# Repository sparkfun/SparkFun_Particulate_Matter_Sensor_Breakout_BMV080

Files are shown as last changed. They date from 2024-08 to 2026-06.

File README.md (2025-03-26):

SparkFun Air Quality PM1/PM2.5/PM10 Sensor - BMV080 (Qwiic)
========================================

SparkFun Air Quality PM1/PM2.5/PM10 Sensor - BMV080 (Qwiic) (https://www.sparkfun.com/sparkfun-air-quality-pm1-pm2-5-pm10-sensor-bmv080-qwiic.html)

[*SparkFun Air Quality PM1/PM2.5/PM10 Sensor - BMV080 (Qwiic) (SEN-26554)*](https://www.sparkfun.com/sparkfun-air-quality-pm1-pm2-5-pm10-sensor-bmv080-qwiic.html)

The SparkFun Qwiic Particulate Matter Sensor - BMV080 is an ultra-small, fan-less air quality sensor for sensing PM2.5 particulate matter! Within the enclosure is a breakout board that breaks out Bosch's BMV080, the world's smallest PM1 and PM2.5 air quality sensor. The sensing element measures merely 4.2mm x 3.5mm x 3.1mm (W x L x H), which is more than 450 times smaller than any comparable device on the market. The innovative design is based on ultra-compact lasers with integrated photodiodes. The sensor applies sophisticated algorithms to measure PM1 and PM2.5 concentrations directly in free space, without requiring an intrusive fan.

Repository Contents
-------------------

* **.github/workflows** - YAML files used for GitHub Actions and GitHub Pages/mkdocs
* **/Enclosure** - Enclosure files
* **/Hardware** - KiCad design files (.kicad_pcb, .kicad_sch, .kicad_pro)
  * **/Production** - Production panel files (.kicad_pcb)
* **/docs** - Online documentation files
  * **/assets** - Folder containing all the file assets used for product documentation
    * **/board_files** - Copy of design files used for product documentation
    * **/component_documentation** - Datasheets and manuals for hardware components
    * **/img** - Images for product documentation
  * **/github** - Files stating how to contribute and filing issues used for product documentation
  * **/javascript** - Folder containing custom javascript used for product documentation
  * **/stylesheet** - Folder containing CSS files used for product documentation
* **/overrides** - Customization files used for product documentation
  * **/.icons** - Icons used for GitHub used for product documentation
  * **./partials** - Used for product documentation

Documentation
--------------
* **[Library](https://github.com/sparkfun/SparkFun_BMV080_Arduino_Library/)** - Arduino library for the SparkFun Air Quality PM1/PM2.5/PM10 Sensor - BMV080 (Qwiic).
* **[Hookup Guide](https://docs.sparkfun.com/SparkFun_Particulate_Matter_Sensor_Breakout_BMV080)** - Basic hookup guide for the SparkFun Air Quality PM1/PM2.5/PM10 Sensor - BMV080 (Qwiic).

Product Versions
----------------
* [SEN-26554](https://www.sparkfun.com/products/ - SparkFun Air Quality PM1/PM2.5/PM10 Sensor - BMV080 (Qwiic) 

License Information
-------------------

This product is _**open source**_!

Please review the LICENSE.md file for license information.

If you have any questions or concerns on licensing, please contact technical support on our [SparkFun forums](https://community.sparkfun.com/c/community/general-chit-chat/37).

Distributed as-is; no warranty is given.

- Your friends at SparkFun.

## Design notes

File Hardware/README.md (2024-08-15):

SparkFun <PRODUCT NAME> Design Files
=====================================

The .sch and .brd files hare are Eagle CAD schematic and PCB design files from SparkFun Electronics.
A freeware version of Autodesk Eagle can be found [here](https://www.autodesk.com/products/eagle/free-download).

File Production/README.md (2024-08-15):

SparkFun <PRODUCT NAME> Production Files
=========================================

These are the production files SparkFun uses for printing PCBs.

License Information
-------------------
This product is open source! 

The hardware is released under [Creative Commons ShareAlike 4.0 International](https://creativecommons.org/licenses/by-sa/4.0/).

Please use, reuse, and modify these files as you see fit. Please maintain attribution to SparkFun Electronics and release anything derivative under the same license.

Distributed as-is; no warranty is given.

- Your friends at SparkFun.

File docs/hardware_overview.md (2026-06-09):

In this section, we will highlight the hardware and pins that are broken out on the SparkFun Qwiic Air Quality PM1/PM2.5/PM10 Sensor - BMV080. For more information, check out our [Resources and Going Further](../resources/) on the components used for the sensor.

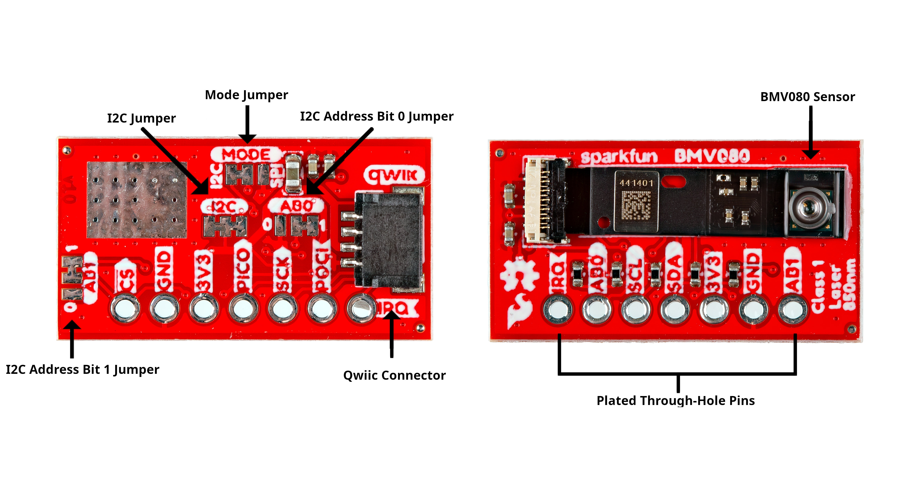
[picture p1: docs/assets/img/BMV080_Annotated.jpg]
Annotated photo of BMV080 Breakout


### BMV080

The breakout board comes with Bosch's BMV080 populated and takes advantage of its flexible cable with the FPC 13-pin 0.33mm connector. The sensor is an ultra-small, fan-less air quality sensor for sensing PM1, PM2.5 and PM10 concentrations. A special lens allows the laser to pass through the enclosure to take measurements.

!!! Note
    This is a [CLASS 1](https://en.wikipedia.org/wiki/Laser_safety#Class_1) LASER PRODUCT CLASSIFIED IEC 60825-1 2014.

### Power

To power the board, you will need **3.3V**. You can connect a Qwiic cable to the Qwiic connector. Or you could solder directly to the PTHs. Below are the power pins that are broken out on the edge of the board.

* **3V3** - This pin is the voltage input for the board. The recommended input voltage for this pin is 3.3V.
* **GND** - Of course, is the common, ground voltage (0V reference) for the system.

### Qwiic and I<sup>2</sup>C

By default, the communication interface is set to I<sup>2</sup>C with the MODE jumper. The board includes one horizontal Qwiic connector to connect to other Qwiic-enabled I<sup>2</sup>C devices. However, the board still breaks out 0.1"-spaced pins for users who prefer a soldered connection.

* **SCL/SCK** - On the top side, the pin is labeled as SCL. On the bottom side, the pin is labeled as SCK. Thus the pin is used for the I<sup>2</sup>C clock.
* **SDA/PICO** - On the top side, the pin is labeled as SDA. On the bottom side, the pin is labeled as PICO. Thus the pin is used for the I<sup>2</sup>C data.

The default address of the BMV080 is set to **0x57** by default. By configuring AB1 and AB0 jumpers, you can adjust the I<sup>2</sup>C address to an alternative address. For more information, check below under the jumpers.

### Interrupt Pin

The board includes an interrupt pin when the board is set to I<sup>2</sup>C mode.

* **IRQ** &mdash; Short for interrupt. This pin sends an interrupt signal to a microcontroller.

!!! note
    The hardware interrupt of the BMV080 sensor unit cannot be used as trigger
    in duty cycling mode.

### SPI

The BMV080 can also be set to SPI as the communication interface by adjusting the MODE jumper on the back.

* **PICO/SDA** - On the bottom side, the pin is labeled as PICO (i.e. Peripheral In, Controller Out). On the top side, the pin is labeled as SDA.
* **POCI/AB0** - On the bottom side, the pin is labeled as POCI (i.e. Peripheral Out, Controller In). On the top side, the pin is labeled as AB0. When set to SPI mode, make sure to leave AB0 (POCI) open!
* **SCK/SCL** - On the bottom side, the pin is labeled as SCK for the clock. On the tip side, the pin is labeled as SCL.
* <b><span style="text-decoration: overline">CS</span></b> - On the bottom side, the pin is labeled as <span style="text-decoration: overline">CS</span> (i.e. chip select). On the top side, the pin is labeled as AB1. This pin is active low. When set to SPI mode, make sure to leave AB1 (<span style="text-decoration: overline">CS</span>) open!

### Jumpers

!!!note
    If this is your first time working with jumpers, check out the [How to Work with Jumper Pads and PCB Traces](https://learn.sparkfun.com/tutorials/how-to-work-with-jumper-pads-and-pcb-traces/all) tutorial for more information.

The back of the board has four jumpers to configure the board labeled **I<sup>2</sup>C**, **AB0**, **AB1** and **MODE**.

* **I<sup>2</sup>C** - By default, this three-pad jumper is closed. The three way jumper labeled I<sup>2</sup>C connects 3.3V to two 2.2k&ohm; pull-up resistors and to the I<sup>2</sup>C data and clock lines. If multiple devices are connected to the bus with the pull-up resistors enabled, the parallel equivalent resistance will create too strong of a pull-up for the bus to operate correctly. As a general rule of thumb, [disable all but one pair of pull-up resistors](https://learn.sparkfun.com/tutorials/i2c/all#i2c-at-the-hardware-level) if multiple devices are connected to the bus.
* **AB0** - Address jumper 0 when the BMV080 is set to I<sup>2</sup>C mode. This is a multifunctional pin. This is also connected to POCI. By default, the three-pad jumper's center pad is connected to the `1` side
* **AB1** - Address jumper 1 when the BMV080 is set to I<sup>2</sup>C mode. This is a multifunctional pin. This is also connected to <span style="text-decoration: overline">CS</span>. By default, the three-pad jumper's center pad is connected to the `1` side
* **MODE** - By default, this three-pad jumper is closed between the center pad and the pad labeled as I2C. Thus, the communication interface is set to I<sup>2</sup>C. Cutting this trace and adding solder between the center pad and the pad labeled as SPI will configure the communication interface as SPI.

When the SparkFun Qwiic Air Quality Sensor is configured in I2C mode, users have the ability to configure the default address using AB0 and AB1 jumpers. The following table shows the possible I<sup>2</sup>C address based on the jumper configuration.

<div style="text-align: center;">
    <table>
        <tr>
            <th style="text-align: center; border: solid 1px #cccccc;">AB1
            </th>
            <th style="text-align: center; border: solid 1px #cccccc;">AB0
            </th>
            <th style="text-align: center; border: solid 1px #cccccc;">I<sup>2</sup>C Address
            </th>
        </tr>
        <tr>
            <td style="text-align: center; border: solid 1px #cccccc;">0
            </td>
            <td style="text-align: center; border: solid 1px #cccccc;">0
            </td>
            <td style="text-align: center; border: solid 1px #cccccc;">0x54
            </td>
        </tr>
        <tr>
            <td style="text-align: center; border: solid 1px #cccccc;">0
            </td>
            <td style="text-align: center; border: solid 1px #cccccc;">1
            </td>
            <td style="text-align: center; border: solid 1px #cccccc;">0x55
            </td>
        </tr>
        <tr>
            <td style="text-align: center; border: solid 1px #cccccc;">1
            </td>
            <td style="text-align: center; border: solid 1px #cccccc;">0
            </td>
            <td style="text-align: center; border: solid 1px #cccccc;">0x56
            </td>
        </tr>
        <tr>
            <td style="text-align: center; border: solid 1px #cccccc;">1
            </td>
            <td style="text-align: center; border: solid 1px #cccccc;">1
            </td>
            <td style="text-align: center; border: solid 1px #cccccc;"><b>0x57 (default)</b>
            </td>
        </tr>
    </table>
</div>

!!! note
    AB0 is a multifunctional pin! When the SparkFun Qwiic Air Quality Sensor is configured for SPI, make sure to leave AB0 (POCI) open!

### 3D Model

A 3D model of the board and components was exported to a STEP file using KiCad.

<!-- Import the component -->
<script type="module" src="https://ajax.googleapis.com/ajax/libs/model-viewer/3.5.0/model-viewer.min.js"></script>

    <model-viewer src="../assets/3d_model/SparkFun_BMV080_v10_3D_model.glb" camera-controls poster="../assets/3d_model/SparkFun_BMV080_v10_3D_image.jpg" environment-image="legacy" shadow-intensity="1.58" exposure="0.64" shadow-softness="0.24" tone-mapping="neutral" camera-orbit="-46.67deg 57.14deg 153.3m" field-of-view="30deg" style="width: 750px; height: 500px;">
    </model-viewer>

<br />
<div style="text-align: center">
    <a href="../assets/3d_model/SparkFun_BMV080_v10_3D_model.step" target="stp_file" class="md-button">Click Here for the STEP File</a>
</div>

### Board Dimensions

The board measures 0.5" x 0.95" (12.70mm x 24.13mm). The breakout board itself does not have mounting holes though the enclosure has two mounting slots to attach the sensor to your project.

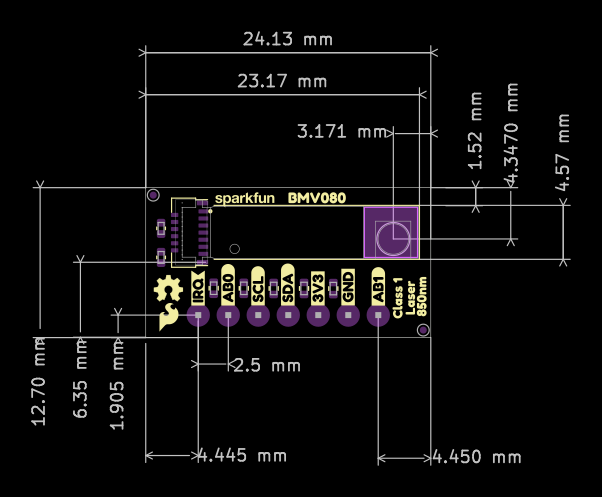
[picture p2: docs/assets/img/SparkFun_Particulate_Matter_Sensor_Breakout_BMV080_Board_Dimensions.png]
Board Dimensions


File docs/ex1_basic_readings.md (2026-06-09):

This example shows how to read the BMV080 via Qwiic when the sensor is configured in continuous mode. The output will show the amount of particulate matter that is detected.

Head to the example 1 from the Arduino IDE's menu (located in **File** **Examples** > **SparkFun BMV080 Arduino Library** > **Example_01_BasicReadings**).

If you have not already, select your Board (if you're following along with the suggested dev board for this tutorial, select **SparkFun ESP32 IoT RedBoard**), and associated COM port. Upload the code to the board and set the [Arduino Serial Monitor](https://learn.sparkfun.com/tutorials/terminal-basics/all#arduino-serial-monitor-windows-mac-linux) to **115200** baud. The Arduino should begin outputting the sensor readings. If the air in front of the sensor is void of particulate matter, you should see `0.00` for each size.

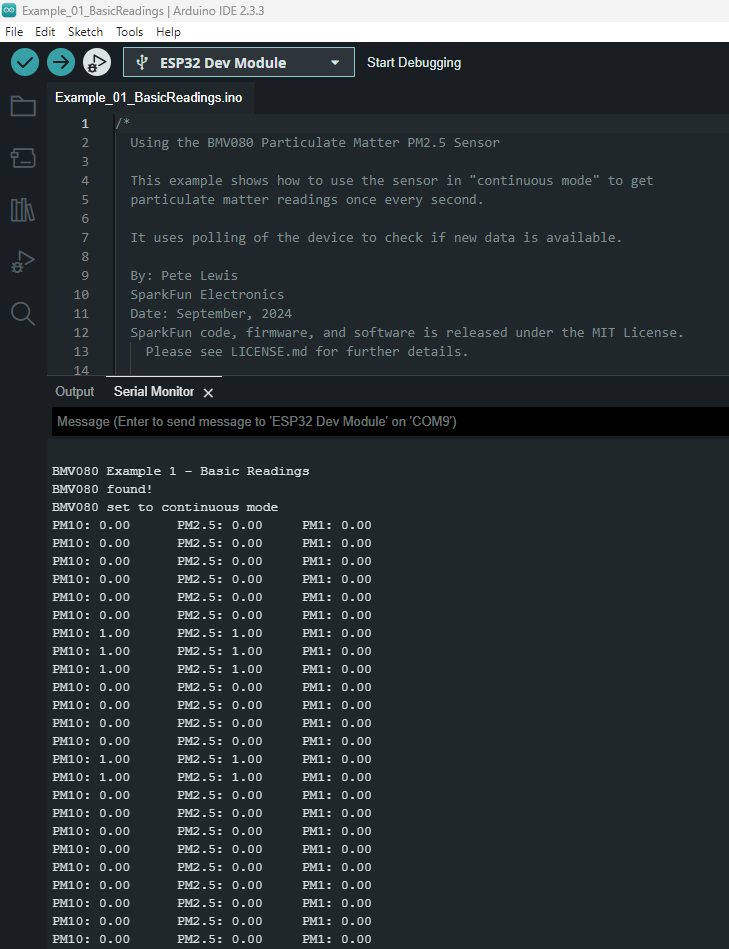
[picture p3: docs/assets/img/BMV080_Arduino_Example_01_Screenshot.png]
Screenshot of Example 1 serial printout


Try placing something like a scented candle or other source of particulate matter near the sensor. You should see the sensor readings jump up depending on the PM size. When the sensor detects an object in front of the it, the code prints out `obstructed`.

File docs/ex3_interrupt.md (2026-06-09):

!!! note
    The interrupt example cannot be used when the BMV080 is in duty cycling mode.

This example shows how to read the BMV080 via Qwiic when the sensor is configured in continuous mode with a hardware interrupt. Similar to the first example, the output will show the amount of particulate matter that is detected. However, the sensor will trigger a hardware interrupt.

Head to the example 3 from the Arduino IDE's menu (located in **File** **Examples** > **SparkFun BMV080 Arduino Library** > **Example_03_Interrupt**).

If you have not already, select your Board and associated COM port. Upload the code to the board and set the [Arduino Serial Monitor](https://learn.sparkfun.com/tutorials/terminal-basics/all#arduino-serial-monitor-windows-mac-linux) to **115200** baud. The Arduino should begin outputting the sensor readings every 20 seconds.

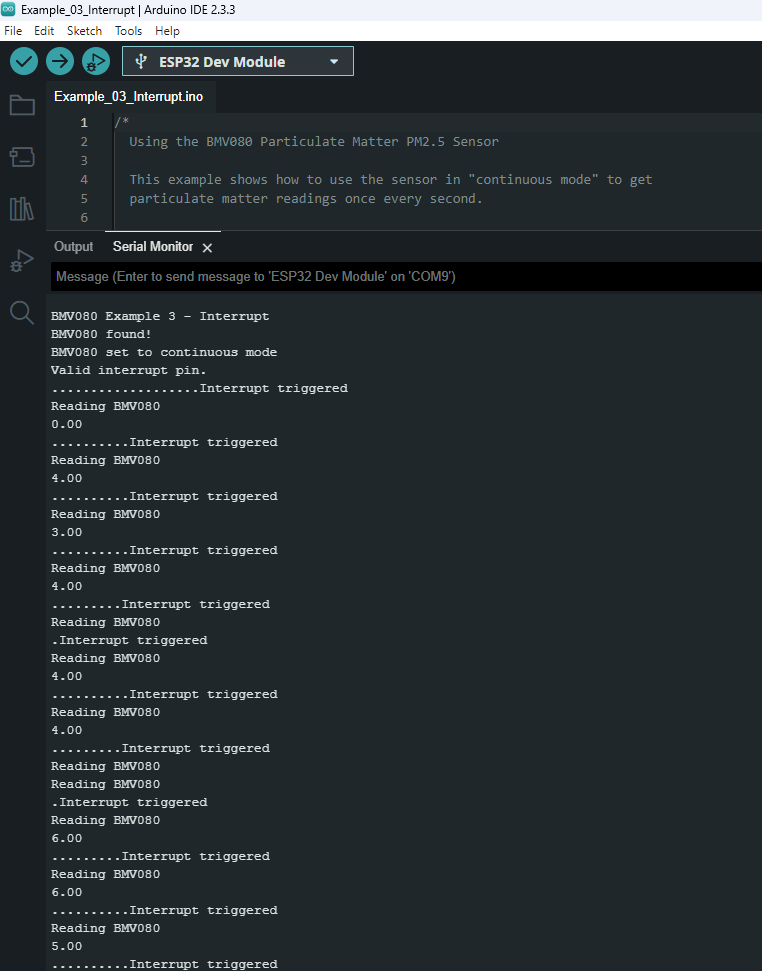
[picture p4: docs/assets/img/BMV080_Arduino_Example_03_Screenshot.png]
Screenshot of Example 3 serial printout


!!! tip
    You can view the timestamp of each sensor readings in the Arduino Serial Monitor by clicking on the "Toggle Timestamp" button. This button is represented as a clock above the baud rate.

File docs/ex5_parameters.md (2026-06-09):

This example shows how to read and set the parameters of the BMV080 via Qwiic. These include `volumetric_mass_density`, `integration_time`, `distribution_id`, `do_obstruction_detection`, `do_vibration_filtering`, and  `measurement_algorithm`. Once these parameters are read and set, this example will then configure the sensor in continuous mode to read particulate mater every second.

Head to the example 5 from the Arduino IDE's menu (located in **File** **Examples** > **SparkFun BMV080 Arduino Library** > **Example_05_Parameters**).

If you have not already, select your Board and associated COM port. Upload the code to the board and set the [Arduino Serial Monitor](https://learn.sparkfun.com/tutorials/terminal-basics/all#arduino-serial-monitor-windows-mac-linux) to **115200** baud. The Arduino should output the paraemters before outputting the sensor readings every second.

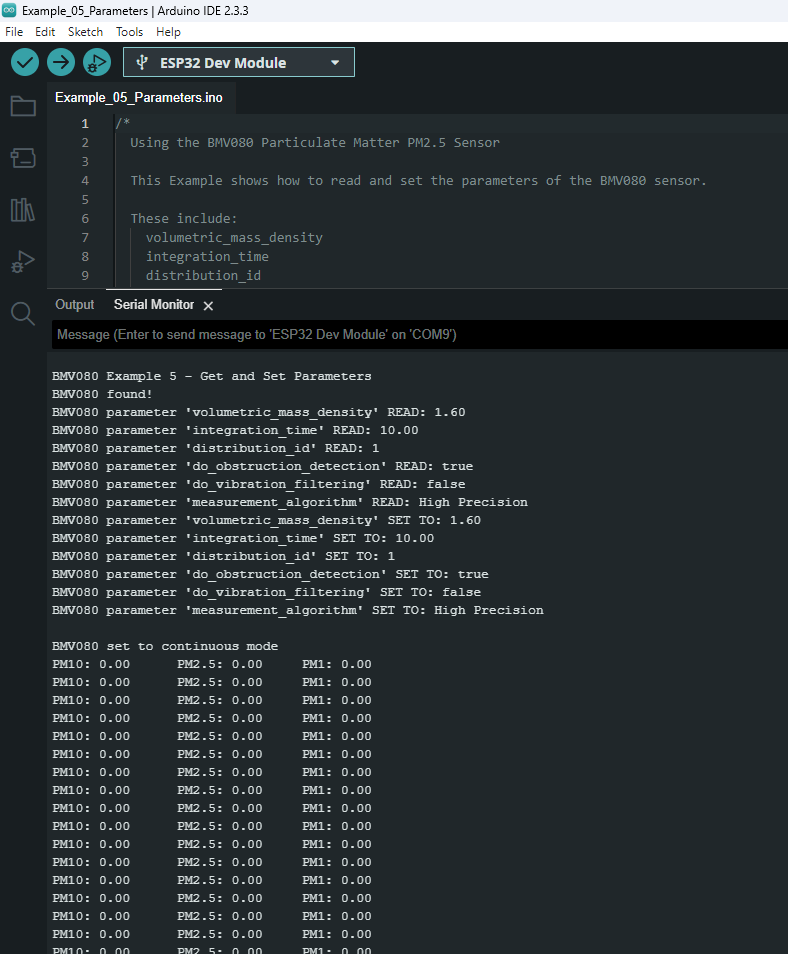
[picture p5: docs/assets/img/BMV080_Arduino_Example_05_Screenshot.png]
Screenshot of Example 5 serial printout


!!! note
    If you do not see the parameters after uploading, you may not have opened the Arduino Serial Monitor when the Arduino output the parameters. Try restarting your Arduino by hitting the reset button.

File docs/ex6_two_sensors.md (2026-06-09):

!!! note
    Make sure to have one sensor using the alternate I<sup>2</sup>C address. In this case, the second BMV080 had AB0 jumper changed to `0`.

This example shows how to read two BMV080 via Qwiic when each sensor is configured in continuous mode. The output will show the amount of particulate matter that is detected from both sensors.

Head to the example 6 from the Arduino IDE's menu (located in **File** **Examples** > **SparkFun BMV080 Arduino Library** > **Example_06_TwoSensors**).

If you have not already, select your Board and associated COM port. Upload the code to the board and set the [Arduino Serial Monitor](https://learn.sparkfun.com/tutorials/terminal-basics/all#arduino-serial-monitor-windows-mac-linux) to **115200** baud. The Arduino should begin outputting the sensor readings from both BMV080s.

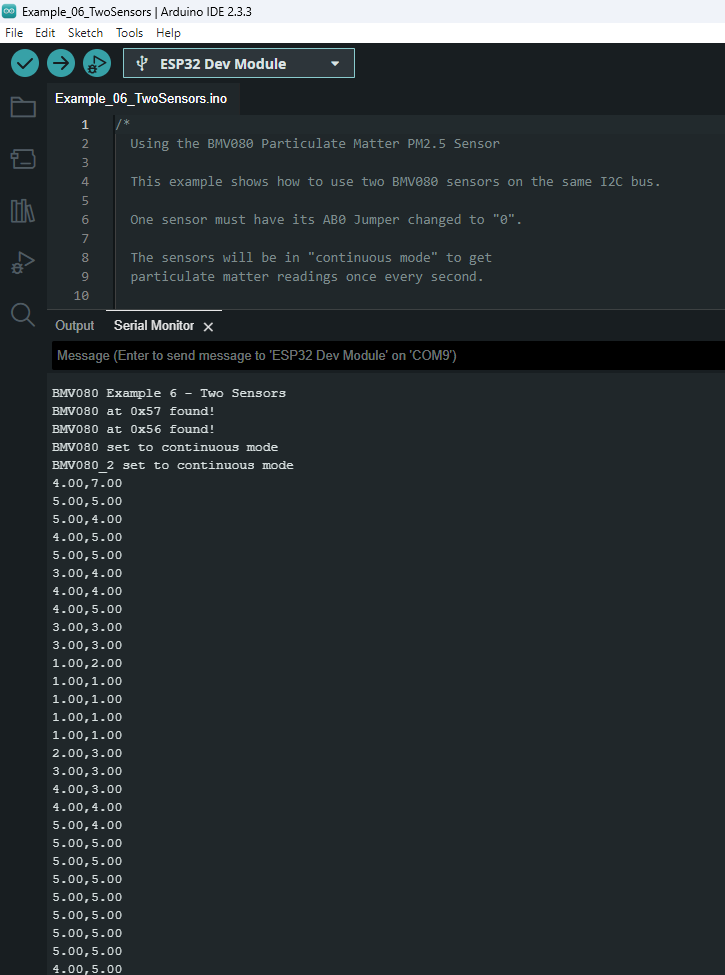
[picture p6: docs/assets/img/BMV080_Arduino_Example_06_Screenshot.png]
Screenshot of Example 6 serial printout


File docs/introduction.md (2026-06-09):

The [SparkFun Qwiic Air Quality PM1/PM2.5/PM10 Sensor - BMV080](https://www.sparkfun.com/catalog/product/view/id/26554) is an ultra-small, fan-less air quality sensor for sensing PM1 and PM2.5 particulate matter! Within the enclosure is a breakout board that breaks out Bosch's BMV080, the world's smallest PM1, PM2.5 and PM10 air quality sensor. The sensing element measures merely 4.2mm x 3.5mm x 3.1mm (W x L x H), which is more than 450 times smaller than any comparable device on the market. The innovative design is based on ultra-compact lasers with integrated photodiodes. The sensor applies sophisticated algorithms to measure PM1, PM2.5 and PM10 concentrations directly in free space, without requiring an intrusive fan.

<div class="grid cards" style="width:500px; margin: 0 auto;" markdown>

-   <a href="https://www.sparkfun.com/catalog/product/view/id/26554">
      <figure markdown>
        SparkFun Qwiic Air Quality PM1/PM2.5/PM10 Sensor - BMV080
      </figure>
    </a>

    ---

    <a href="https://www.sparkfun.com/catalog/product/view/id/26554">
      <b>SparkFun Qwiic Air Quality PM1/PM2.5/PM10 Sensor - BMV080</b>
      <br />
      SEN-26554
      <br />
      [Purchase from SparkFun :fontawesome-solid-cart-plus:](https://www.sparkfun.com/catalog/product/view/id/26554){ .md-button .md-button--primary }
    </a>
</div>

In this tutorial, we'll go over the hardware and how to hookup the sensor to an Arduino. We will also go over examples from the Arduino Library to get started.

### Required Materials

This tutorial is written to use the SparkFun Particulate Matter Sensor - BMV080 with the SparkFun IoT RedBoard - ESP32. If you want to follow along exactly with the tutorial, you'll need the BMV080 along with the following items:

<div class="grid cards col-4" markdown>

<!-- ----------WHITE SPACE BETWEEN PRODUCTS---------- -->
-   <a href="https://www.sparkfun.com/usb-3-1-cable-a-to-c-3-foot.html">
      <figure markdown>
        USB 3.1 Cable A to C - 3 Foot
      </figure>
    </a>

    ---

    <a href="https://www.sparkfun.com/usb-3-1-cable-a-to-c-3-foot.html">
      <b>USB 3.1 Cable A to C - 3 Foot</b>
      <br />
      CAB-14743
    </a>
<!-- ----------WHITE SPACE BETWEEN PRODUCTS---------- -->
-   <a href="https://www.sparkfun.com/sparkfun-iot-redboard-esp32-development-board.html">
      <figure markdown>
        SparkFun IoT RedBoard - ESP32 Development Board
      </figure>
    </a>

    ---

    <a href="https://www.sparkfun.com/sparkfun-iot-redboard-esp32-development-board.html">
      <b>SparkFun IoT RedBoard - ESP32 Development Board</b>
      <br />
      WRL-19177
    </a>
<!-- ----------WHITE SPACE BETWEEN PRODUCTS---------- -->
-   <a href="https://www.sparkfun.com/flexible-qwiic-cable-200mm.html">
      <figure markdown>
        Flexible Qwiic Cable - 200mm
      </figure>
    </a>

    ---

    <a href="https://www.sparkfun.com/flexible-qwiic-cable-200mm.html">
      <b>Flexible Qwiic Cable - 200mm</b>
      <br />
      PRT-17258
    </a>
<!-- ----------WHITE SPACE BETWEEN PRODUCTS---------- -->
</div>

### Other Microcontrollers

We recommend using any board with an ESP32 (such as the ESP32-WROOM, ESP32-S2, and ESP32-S3). We'll be using the RedBoard IoT RedBoard - ESP32 Development Board for the examples in this tutorial.

<div class="grid cards col-4" markdown>
<!-- ----------WHITE SPACE BETWEEN PRODUCTS---------- -->
-   <a href="https://www.sparkfun.com/sparkfun-iot-redboard-esp32-development-board.html">
      <figure markdown>
        SparkFun IoT RedBoard - ESP32 Development Board
      </figure>
    </a>

    ---

    <a href="https://www.sparkfun.com/sparkfun-iot-redboard-esp32-development-board.html">
      <b>SparkFun IoT RedBoard - ESP32 Development Board</b>
      <br />
      WRL-19177
    </a>
<!-- ----------WHITE SPACE BETWEEN PRODUCTS---------- -->
-   <a href="https://www.sparkfun.com/sparkfun-thing-plus-esp32-wroom-usb-c.html">
      <figure markdown>
        SparkFun Thing Plus - ESP32 WROOM (USB-C)
      </figure>
    </a>

    ---

    <a href="https://www.sparkfun.com/sparkfun-thing-plus-esp32-wroom-usb-c.html">
      <b>SparkFun Thing Plus - ESP32 WROOM (USB-C)</b>
      <br />
      WRL-20168
    </a>
<!-- ----------WHITE SPACE BETWEEN PRODUCTS---------- -->
-   <a href="https://www.sparkfun.com/sparkfun-thing-plus-esp32-s2-wroom.html">
      <figure markdown>
        SparkFun Thing Plus - ESP32-S2 WROOM
      </figure>
    </a>

    ---

    <a href="https://www.sparkfun.com/sparkfun-thing-plus-esp32-s2-wroom.html">
      <b>SparkFun Thing Plus - ESP32-S2 WROOM</b>
      <br />
      WRL-17743
    </a>
<!-- ----------WHITE SPACE BETWEEN PRODUCTS---------- -->
-   <a href="https://www.sparkfun.com/sparkfun-thing-plus-esp32-s3.html">
      <figure markdown>
        SparkFun Thing Plus - ESP32-S3
      </figure>
    </a>

    ---

    <a href="https://www.sparkfun.com/sparkfun-thing-plus-esp32-s3.html">
      <b>SparkFun Thing Plus - ESP32-S3</b>
      <br />
      WRL-24408
    </a>
<!-- ----------WHITE SPACE BETWEEN PRODUCTS---------- -->
</div>

### Qwiic Accessories

For those that want to take advantage of the Qwiic connector, you'll want to grab a Qwiic cable. Besides the one listed earlier, there are a variety of other cable lengths available in the SparkFun catalog to choose from.

<div class="grid cards col-4" markdown>
<!-- ----------WHITE SPACE BETWEEN PRODUCTS---------- -->
-   <a href="https://www.sparkfun.com/products/15081">
      <figure markdown>
        SparkFun Qwiic Cable Kit
      </figure>
    </a>

    ---

    <a href="https://www.sparkfun.com/products/15081">
      <b>SparkFun Qwiic Cable Kit</b>
      <br />
      KIT-15081
    </a>
<!-- ----------WHITE SPACE BETWEEN PRODUCTS---------- -->
-   <a href="https://www.sparkfun.com/products/14427">
      <figure markdown>
        Qwiic Cable - 100mm
      </figure>
    </a>

    ---

    <a href="https://www.sparkfun.com/products/14427">
      <b>Qwiic Cable - 100mm</b>
      <br>
      PRT-14427
    </a>
<!-- ----------WHITE SPACE BETWEEN PRODUCTS---------- -->
-   <a href="https://www.sparkfun.com/products/14429">
      <figure markdown>
        Qwiic Cable - 500mm
      </figure>
    </a>

    ---

    <a href="https://www.sparkfun.com/products/14429">
      <b>Qwiic Cable - 500mm</b>
      <br />
      PRT-14429
    </a>
<!-- ----------WHITE SPACE BETWEEN PRODUCTS---------- -->
-   <a href="https://www.sparkfun.com/products/14425">
      <figure markdown>
        Qwiic Cable - Breadboard Jumper (4-pin)
      </figure>
    </a>

    ---

    <a href="https://www.sparkfun.com/products/14425">
      <b>Qwiic Cable - Breadboard Jumper (4-pin)</b>
      <br />
      PRT-14425
    </a>
<!-- ----------WHITE SPACE BETWEEN PRODUCTS---------- -->
</div>

You'll also want a Qwiic MultiPort when daisy chaining more than one BMV080 or adding additional Qwiic-enabled devices. Adding displays will allow you to view the amount of particulate mater in the air.

<div class="grid cards col-4" markdown>
<!-- ----------WHITE SPACE BETWEEN PRODUCTS---------- -->
-   <a href="https://www.sparkfun.com/products/18012">
      <figure markdown>
        SparkFun Qwiic MultiPort
      </figure>
    </a>

    ---

    <a href="https://www.sparkfun.com/products/18012">
      <b>SparkFun Qwiic MultiPort</b>
      <br />
      BOB-18012
    </a>
<!-- ----------WHITE SPACE BETWEEN PRODUCTS---------- -->
-   <a href="https://www.sparkfun.com/products/16916">
      <figure markdown>
        SparkFun Qwiic Alphanumeric Display - Red
      </figure>
    </a>

    ---

    <a href="https://www.sparkfun.com/products/16916">
      <b>SparkFun Qwiic Alphanumeric Display - Red</b>
      <br />
      COM-16916
    </a>
<!-- ----------WHITE SPACE BETWEEN PRODUCTS---------- -->
-   <a href="https://www.sparkfun.com/products/23453">
      <figure markdown>
        SparkFun Qwiic OLED - (1.3in., 128x64)
      </figure>
    </a>

    ---

    <a href="https://www.sparkfun.com/products/23453">
      <b>SparkFun Qwiic OLED - (1.3in., 128x64)</b>
      <br />
      LCD-23453
    </a>
<!-- ----------WHITE SPACE BETWEEN PRODUCTS---------- -->
</div>

### Tools (Optional)

!!! note
    When soldering directly to the PTHs, you will need to be careful of the 3D printed enclosure! You will want to carefully remove the board from the enclosure before soldering.

You will need a soldering iron, solder, and [general soldering accessories](https://www.sparkfun.com/categories/49) for a secure connection when using the plated through holes.

<div class="grid cards col-4" markdown>

-   <a href="https://www.sparkfun.com/products/14456">
      <figure markdown>
        Soldering Iron - 60W (Adjustable Temperature)
      </figure>
    </a>

    ---

    <a href="https://www.sparkfun.com/products/14456">
      <b>Soldering Iron - 60W (Adjustable Temperature)</b>
      <br />
      TOL-14456
    </a>
<!-- ----------WHITE SPACE BETWEEN PRODUCTS---------- -->
-   <a href="https://www.sparkfun.com/products/9163">
      <figure markdown>
        Solder Lead Free - 15-gram Tube
      </figure>
    </a>

    ---

    <a href="https://www.sparkfun.com/products/9163">
      <b>Solder Lead Free - 15-gram Tube</b>
      <br>
      TOL-09163
    </a>
<!-- ----------WHITE SPACE BETWEEN PRODUCTS---------- -->
-   <a href="https://www.sparkfun.com/products/11375">
      <figure markdown>
        Hook-Up Wire - Assortment (Stranded, 22 AWG)
      </figure>
    </a>

    ---

    <a href="https://www.sparkfun.com/products/11375">
      <b>Hook-Up Wire - Assortment (Stranded, 22 AWG)</b>
      <br />
      PRT-11375
    </a>
<!-- ----------WHITE SPACE BETWEEN PRODUCTS---------- -->
-   <a href="https://www.sparkfun.com/products/12630">
      <figure markdown>
        Wire Strippers - 30AWG (Hakko)
      </figure>
    </a>

    ---

    <a href="https://www.sparkfun.com/products/12630">
      <b>Wire Strippers - 30AWG (Hakko)</b>
      <br />
      TOL-12630
    </a>
<!-- ----------WHITE SPACE BETWEEN PRODUCTS---------- -->
-   <a href="https://www.sparkfun.com/products/11952">
      <figure markdown>
        Flush Cutters - Hakko
      </figure>
    </a>

    ---

    <a href="https://www.sparkfun.com/products/11952">
      <b>Flush Cutters - Hakko</b>
      <br />
      TOL-11952
    </a>
<!-- ----------WHITE SPACE BETWEEN PRODUCTS---------- -->
-   <a href="https://www.sparkfun.com/hobby-knife.html">
      <figure markdown>
        Hobby Knife
      </figure>
    </a>

    ---

    <a href="https://www.sparkfun.com/hobby-knife.html">
      <b>Hobby Knife</b>
      <br />
      TOL-09200
    </a>
<!-- ----------WHITE SPACE BETWEEN PRODUCTS---------- -->
</div>

For users that are using the BMV080 in SPI mode or mounting the enclosure, make sure to grab the iFixit Moray Driver Kit. A precision flathead with 0.1mm tip is needed to remove the sensor from the enclosure. We also recommend using Phillips screwdriver with #0 tip and 4-40 standoffs when mounting the enclosure.

<div class="grid cards col-4" markdown>
<!-- ----------WHITE SPACE BETWEEN PRODUCTS---------- -->
-   <a href="https://www.sparkfun.com/products/25568">
      <figure markdown>
        iFixit Moray Driver Kit
      </figure>
    </a>

    ---

    <a href="https://www.sparkfun.com/products/25568">
      <b>iFixit Moray Driver Kit</b>
      <br />
      TOL-14456
    </a>
<!-- ----------WHITE SPACE BETWEEN PRODUCTS---------- -->

-   <a href="https://www.sparkfun.com/products/10927">
      <figure markdown>
        Standoff - Nylon (4-40; 3/8in; 10 pack)
      </figure>
    </a>

    ---

    <a href="https://www.sparkfun.com/products/10927">
      <b>Standoff - Nylon (4-40; 3/8"; 10 pack)</b>
      <br />
      TOL-14456
    </a>
<!-- ----------WHITE SPACE BETWEEN PRODUCTS---------- -->
-   <a href="https://www.sparkfun.com/products/10453">
      <figure markdown>
        Screw - Phillips Head (1/4
      <br />
      PRT-14456
    </a>
<!-- ----------WHITE SPACE BETWEEN PRODUCTS---------- -->
</div>

### Prototyping Accessories (Optional)

!!! note
    Due to the size of the 3D printed enclosure, you will not be able to place the sensor on a breadboard. We recommend using M/F jumper wires should you decide to solder male header pins on the sensor. Of course, when soldering the sensor to a protoboard, you could solder to the other side of the protoboard to access the pins.

Depending on your setup, you may want to use IC hooks for a temporary connection when the sensor is removed from enclosure. However, you will want to solder header pins to connect devices to the plated through holes for a secure connection. We opted for straight male headers for the SparkFun Qwiic Air Quality PM1/PM2.5/PM10 Sensor - BMV080 as well as M/F jumpers to connect to the RedBoard IoT Development Board to reduce the amount of soldering.

<div class="grid cards col-4" markdown>
<!-- ----------WHITE SPACE BETWEEN PRODUCTS---------- -->
-   <a href="https://www.sparkfun.com/products/9741">
      <figure markdown>
        IC Hook with Pigtail
      </figure>
    </a>

    ---

    <a href="https://www.sparkfun.com/products/9741">
      <b>IC Hook with Pigtail</b>
      <br>
      CAB-09741
    </a>
<!-- ----------WHITE SPACE BETWEEN PRODUCTS---------- -->
-   <a href="https://www.sparkfun.com/products/116">
      <figure markdown>
        Break Away Headers - Straight
      </figure>
    </a>

    ---

    <a href="https://www.sparkfun.com/products/116">
      <b>Break Away Headers - Straight</b>
      <br />
      PRT-00116
    </a>
<!-- ----------WHITE SPACE BETWEEN PRODUCTS---------- -->
-   <a href="https://www.sparkfun.com/products/9140">
      <figure markdown>
        Jumper Wires Premium 6
      <br />
      PRT-09140
    </a>
<!-- ----------WHITE SPACE BETWEEN PRODUCTS---------- -->
</div>

### Suggested Reading

If you aren't familiar with the Qwiic Connection System, we recommend reading [here for an overview](https://www.sparkfun.com/qwiic).

<div style="text-align: center">
  <table style="border-style:none">
    <tr>
     <td style="text-align: center; vertical-align: middle;">
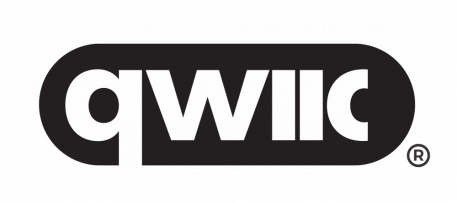
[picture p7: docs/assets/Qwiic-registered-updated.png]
Qwiic Connection System Click to learn more about the Qwiic Connection System!
     <div style="text-align: center">
     </div>
    </td>
    </tr>
    <tr>
      <td style="text-align: center; vertical-align: middle;"><div style="text-align: center"><i><a href="https://www.sparkfun.com/qwiic">Qwiic Connection System</a></i></div></td>
    </tr>
  </table>
</div>

If you aren’t familiar with the following concepts, we also recommend checking out a few of these tutorials before continuing.

<div class="grid cards col-4" markdown>
<!-- ----------WHITE SPACE BETWEEN GRID CARDS---------- -->
-   <a href="https://learn.sparkfun.com/tutorials/installing-arduino-ide">
      <figure markdown>
        Installing Arduino IDE
      </figure>
    </a>

    ---

    <a href="https://learn.sparkfun.com/tutorials/installing-arduino-ide">
      <b>Installing Arduino IDE</b>
    </a>
<!-- ----------WHITE SPACE BETWEEN GRID CARDS---------- -->
-   <a href="https://learn.sparkfun.com/tutorials/installing-board-definitions-in-the-arduino-ide">
      <figure markdown>
        Installing Board Definitions in the Arduino IDE
      </figure>
    </a>

    ---

    <a href="https://learn.sparkfun.com/tutorials/installing-board-definitions-in-the-arduino-ide">
      <b>Installing Board Definitions in the Arduino IDE</b>
    </a>
<!-- ----------WHITE SPACE BETWEEN GRID CARDS---------- -->
-   <a href="https://learn.sparkfun.com/tutorials/iot-redboard-esp32-development-board-hookup-guide">
      <figure markdown>
        IoT RedBoard ESP32 Development Board Hookup Guide
      </figure>
    </a>

    ---

    <a href="https://learn.sparkfun.com/tutorials/iot-redboard-esp32-development-board-hookup-guide">
      <b>IoT RedBoard ESP32 Development Board Hookup Guide</b>
    </a>
<!-- ----------WHITE SPACE BETWEEN GRID CARDS---------- -->
-   <a href="https://learn.sparkfun.com/tutorials/how-to-install-ch340-drivers/all">
      <figure markdown>
        How to Install CH340 Drivers
      </figure>
    </a>

    ---

    <a href="https://learn.sparkfun.com/tutorials/how-to-install-ch340-drivers/all">
      <b>How to Install CH340 Drivers</b>
    </a>
<!-- ----------WHITE SPACE BETWEEN GRID CARDS---------- -->
-   <a href="https://learn.sparkfun.com/tutorials/i2c">
      <figure markdown>
        I2C
      </figure>
    </a>

    ---

    <a href="https://learn.sparkfun.com/tutorials/i2c">
      <b>I2C</b>
    </a>
<!-- ----------WHITE SPACE BETWEEN GRID CARDS---------- -->
-   <a href="https://learn.sparkfun.com/tutorials/serial-peripheral-interface-spi">
      <figure markdown>
        Serial Peripheral Interface (SPI)
      </figure>
    </a>

    ---

    <a href="https://learn.sparkfun.com/tutorials/serial-peripheral-interface-spi">
      <b>Serial Peripheral Interface (SPI)</b>
    </a>
<!-- ----------WHITE SPACE BETWEEN GRID CARDS---------- -->
-   <a href="https://learn.sparkfun.com/tutorials/logic-levels">
      <figure markdown>
        Logic Levels
      </figure>
    </a>

    ---

    <a href="https://learn.sparkfun.com/tutorials/logic-levels">
      <b>Logic Levels</b>
    </a>
<!-- ----------WHITE SPACE BETWEEN GRID CARDS---------- -->
</div>

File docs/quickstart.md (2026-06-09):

In this Quick Start guide we'll show how to get air quality measurements from the SparkFun Air Quality PM1/PM2.5/PM10 Sensor - BMV080 (Qwiic) and IoT RedBoard - ESP32 using the Arduino IDE. This guide assumes users are familiar with the Arduino IDE and Arduino development boards. You'll need the following items to follow along with this guide:

* [SparkFun Air Quality PM2/PM2.5/PM10 Sensor - BMV080 (Qwiic)](https://www.sparkfun.com/sparkfun-air-quality-pm1-pm2-5-pm10-sensor-bmv080-qwiic.html)
* [SparkFun IoT RedBoard - ESP32](https://www.sparkfun.com/sparkfun-iot-redboard-esp32-development-board.html)
* [Qwiic Cable](https://www.sparkfun.com/flexible-qwiic-cable-100mm.html)
* [USB-C Cable](https://www.sparkfun.com/reversible-usb-a-to-c-cable-0-8m.html)

If you're unfamiliar with any of the concepts covered here or would like more information about the Air Quality PM1/PM2.5/PM10 Sensor - BMV080 (Qwiic) read on to the following sections for detailed information about the BMV080 along with instructions on assembling it into a circuit, removing the breakout board from the enclosure and installing and using the BMV080 Arduino library.

## Basic Assembly

Start by connecting the Air Quality Sensor - BMV080 to the IoT RedBoard - ESP32 using a Qwiic cable and then connect the IoT RedBoard - ESP23 to your computer with a USB-C cable:

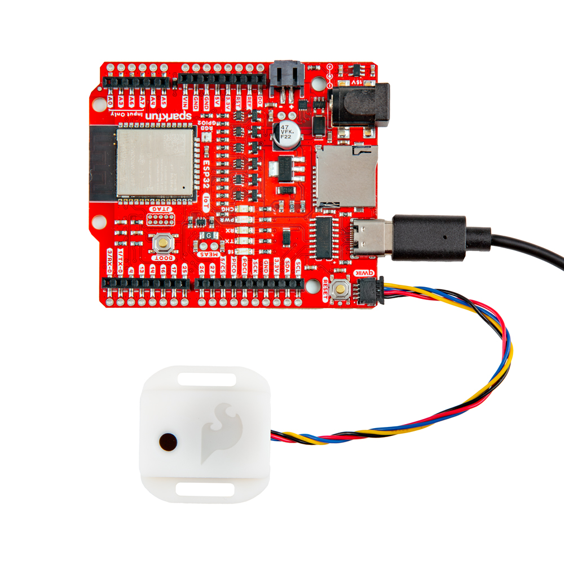
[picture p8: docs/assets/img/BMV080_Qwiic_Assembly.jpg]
Photo of completed Qwiic assembly


## Installing SparkFun BMV080 Arduino Library & Bosch BMV080 SDK Files

The SparkFun BMV080 Arduino library requires some manual installation as it does **not** include the required files from BMV080 SDK from Bosch. Users will need to download the SDK from [this page](https://www.bosch-sensortec.com/products/environmental-sensors/particulate-matter-sensor/bmv080/#documents) and then manually place the necessary files in the SparkFun BMV080 Arduino library folder. The tables below outlines where to find the Arduino Libraries folder along with the filepaths and filenames of all SDK files you'll need to copy into the SparkFun BMV080 Arduino folder:

### Library Install Directory

| OS | Directory|
|---|---|
|macOS | $HOME/Documents/Arduino/libraries/SparkFun_BMV080_Arduino_Library|
|Windows | $HOME\Documents\Arduino\libraries\SparkFun_BMV080_Arduino_Library|
|Linux| $HOME/Arduino/libraries/SparkFun_BMV080_Arduino_Library|

### Files to copy and locations to copy to

From the Bosch SDK, the following files are copied into the specified library locations.

|Bosch SDK File | SparkFun BMV080 Arduino Library Directory|
|--|--|
|api/inc/bmv080.h| src/sfTk/bmv080.h|
|api/inc/bmv080_defs.h| src/sfTk/bmv080_defs.h|
|api/api/lib/xtensa_esp32/xtensa_esp32_elf_gcc/release/lib_bmv080.a | src/esp32/lib_bmv080.a|
|api/api/lib/xtensa_esp32/xtensa_esp32_elf_gcc/release/lib_postProcessor.a | src/esp32/lib_postProcessor.a|
|api/api/lib/xtensa_esp32s2/xtensa_esp32s2_elf_gcc/release/lib_postProcessor.a | src/esp32s2/lib_postProcessor.a|
|api/api/lib/xtensa_esp32s2/xtensa_esp32s2_elf_gcc/release/lib_bmv080.a | src/esp32s2/lib_bmv080.a|
|api/api/lib/xtensa_esp32s3/xtensa_esp32s3_elf_gcc/release/lib_postProcessor.a | src/esp32s3/lib_postProcessor.a|
|api/api/lib/xtensa_esp32s3/xtensa_esp32s3_elf_gcc/release/lib_bmv080.a | src/esp32s3/lib_bmv080.a|
|api/api/lib/arm_cortex_m0plus/xarm_none_eabi_gcc/release/lib_postProcessor.a | src/cortex-m0plus/lib_postProcessor.a|
|api/api/lib/arm_cortex_m0plus/arm_none_eabi_gcc/release/lib_bmv080.a | src/cortex-m0plus/lib_bmv080.a|
|api/api/lib/arm_cortex_m33f/xarm_none_eabi_gcc/release/lib_postProcessor.a | src/cortex-m33/lib_postProcessor.a|
|api/api/lib/arm_cortex_m33f/arm_none_eabi_gcc/release/lib_bmv080.a | src/cortex-m33/lib_bmv080.a|
|api/api/lib/arm_cortex_m4/xarm_none_eabi_gcc/release/lib_postProcessor.a | src/cortex-m4/lib_postProcessor.a|
|api/api/lib/arm_cortex_m4/arm_none_eabi_gcc/release/lib_bmv080.a | src/cortex-m4/lib_bmv080.a|
|api/api/lib/arm_cortex_m4f/xarm_none_eabi_gcc/release/lib_postProcessor.a | src/cortex-m4f/lib_postProcessor.a|
|api/api/lib/arm_cortex_m4f/arm_none_eabi_gcc/release/lib_bmv080.a | src/cortex-m4f/lib_bmv080.a|

## Arduino Example 1 - Basic Readings

This example demonstrates the basics of initializing and reading air quality data from the BMV080 over I<sup>2</sup>C. Run "Example 01 - Basic Readings" by completing the following steps:

* If necessary, open the [Boards Manager](https://docs.arduino.cc/software/ide-v2/tutorials/ide-v2-board-manager/) tool, search for "SparkFun ESP32" and install the latest version of the SparkFun ESP boards.
* In the Examples menu, open **Example_01_BasicReadings**.
* Select the Board (SparkFun ESP32 IoT RedBoard) and Port and click "Upload".
* Open the [Serial Monitor](https://docs.arduino.cc/software/ide-v2/tutorials/ide-v2-serial-monitor) with the baud set to **115200** to view particulate matter readings from the BMV080.

Screenshot of serial monitor printing out air quality readings

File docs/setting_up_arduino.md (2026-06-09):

!!! arduino
    This example assumes you are using the latest version of the Arduino IDE on your desktop. If this is your first time using Arduino IDE, library, or board add-on, please review the following tutorials.

    - [Installing the Arduino IDE](https://learn.sparkfun.com/tutorials/installing-arduino-ide)
    - [Installing an Arduino Library](https://learn.sparkfun.com/tutorials/installing-an-arduino-library)
    - [Installing Board Definitions in the Arduino IDE](https://learn.sparkfun.com/tutorials/installing-board-definitions-in-the-arduino-ide)

## SparkFun BMV080 Arduino Library Install

SparkFun has written a library using Bosch's API to work with the BMV080! You can obtain this library through the Arduino Library Manager by searching for "**SparkFun BMV080**". Find the one written by SparkFun Electronics and install the latest version. Users who prefer to manually install the library can get it from the [GitHub Repository](https://github.com/sparkfun/SparkFun_BMV080_Arduino_Library) or download the .ZIP by clicking the button below:

[SparkFun BMV080 Arduino Library (ZIP)](https://github.com/sparkfun/SparkFun_BMV080_Arduino_Library/archive/refs/heads/feature/remove-bosch-sdk.zip){ .md-button .md-button--primary }

!!! note
    The SparkFun BMV080 Arduino Library uses the [SparkFun Toolkit](https://github.com/sparkfun/SparkFun_Toolkit) as a dependency. This should automatically download when installing the library using the Arduino Library Manager. For users that are installing the BMV080 library manually, make sure to download the SparkFun Toolkit as well. At the time of writing, we were using the following Arduino Libraries, firmware binaries, board add-ons.

     * Arduino Libraries
        * **SparkFun BMV080 Arduino Library**
        * **SparkFun Toolkit v1.0.0**
     * Board Definitions
        * **esp32 by Espressif v3.0.1** for the IoT RedBoard - ESP32.

## Adding the BMV080 SDK

The SparkFun BMV080 Arduino library requires some manual installation as it does **not** include the required files from BMV080 SDK from Bosch. After installing the SparkFun library, users need to download the SDK from [this page](https://www.bosch-sensortec.com/products/environmental-sensors/particulate-matter-sensor/bmv080/#documents) and then manually place the necessary files in the SparkFun BMV080 Arduino library folder. The tables below outlines where to find the Arduino Libraries folder along with the filepaths and filenames of all SDK files you'll need to copy into the SparkFun BMV080 Arduino folder:

### Library Install Directory

| OS | Directory|
|---|---|
|macOS | $HOME/Documents/Arduino/libraries/SparkFun_BMV080_Arduino_Library|
|Windows | $HOME\Documents\Arduino\libraries\SparkFun_BMV080_Arduino_Library|
|Linux| $HOME/Arduino/libraries/SparkFun_BMV080_Arduino_Library|

### Files to copy and locations to copy to

From the Bosch SDK, the following files are copied into the specified library locations.

|Bosch SDK File | SparkFun BMV080 Arduino Library Directory|
|--|--|
|api/inc/bmv080.h| src/sfTk/bmv080.h|
|api/inc/bmv080_defs.h| src/sfTk/bmv080_defs.h|
|api/api/lib/xtensa_esp32/xtensa_esp32_elf_gcc/release/lib_bmv080.a | src/esp32/lib_bmv080.a|
|api/api/lib/xtensa_esp32/xtensa_esp32_elf_gcc/release/lib_postProcessor.a | src/esp32/lib_postProcessor.a|
|api/api/lib/xtensa_esp32s2/xtensa_esp32s2_elf_gcc/release/lib_postProcessor.a | src/esp32s2/lib_postProcessor.a|
|api/api/lib/xtensa_esp32s2/xtensa_esp32s2_elf_gcc/release/lib_bmv080.a | src/esp32s2/lib_bmv080.a|
|api/api/lib/xtensa_esp32s3/xtensa_esp32s3_elf_gcc/release/lib_postProcessor.a | src/esp32s3/lib_postProcessor.a|
|api/api/lib/xtensa_esp32s3/xtensa_esp32s3_elf_gcc/release/lib_bmv080.a | src/esp32s3/lib_bmv080.a|
|api/api/lib/arm_cortex_m0plus/xarm_none_eabi_gcc/release/lib_postProcessor.a | src/cortex-m0plus/lib_postProcessor.a|
|api/api/lib/arm_cortex_m0plus/arm_none_eabi_gcc/release/lib_bmv080.a | src/cortex-m0plus/lib_bmv080.a|
|api/api/lib/arm_cortex_m33f/xarm_none_eabi_gcc/release/lib_postProcessor.a | src/cortex-m33/lib_postProcessor.a|
|api/api/lib/arm_cortex_m33f/arm_none_eabi_gcc/release/lib_bmv080.a | src/cortex-m33/lib_bmv080.a|
|api/api/lib/arm_cortex_m4/xarm_none_eabi_gcc/release/lib_postProcessor.a | src/cortex-m4/lib_postProcessor.a|
|api/api/lib/arm_cortex_m4/arm_none_eabi_gcc/release/lib_bmv080.a | src/cortex-m4/lib_bmv080.a|
|api/api/lib/arm_cortex_m4f/xarm_none_eabi_gcc/release/lib_postProcessor.a | src/cortex-m4f/lib_postProcessor.a|
|api/api/lib/arm_cortex_m4f/arm_none_eabi_gcc/release/lib_bmv080.a | src/cortex-m4f/lib_bmv080.a|

## BMV080 Board Limitations

The SparkFun BMV080 Arduino Library only works with the following SparkFun boards:

* [IoT RedBoard - ESP32](https://www.sparkfun.com/sparkfun-iot-redboard-esp32-development-board.html)
* [Thing Plus - ESP32 WROOM (USB-C)](https://www.sparkfun.com/sparkfun-thing-plus-esp32-wroom-usb-c.html)
* [Thing Plus - ESP32-S2 WROOM](https://www.sparkfun.com/sparkfun-thing-plus-esp32-s2-wroom.html)
* [Thing Plus - RA6M5](https://www.sparkfun.com/sparkfun-thing-plus-ra6m5.html)

Now that we have our library and board add-on installed, we can start experimenting with the breakout board. For the scope of this tutorial, we will highlight the examples to get started. From there we will be able to build our own custom code to integrate the development board into a project.

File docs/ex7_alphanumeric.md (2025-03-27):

This example shows how to read the BMV080 via Qwiic when the sensor is configured in duty cycle mode and outputs the readings to display them on a Qwiic Alphanumeric display connected over a Qwiic daisy-chain. You'll need a [Qwii Alphanumeric Display](https://www.sparkfun.com/sparkfun-qwiic-alphanumeric-display-red.html) to run this example.

Head to the example 7 from the Arduino IDE's menu (located in **File** **Examples** > **SparkFun BMV080 Arduino Library** > **Example_07_Demo_Alphanumeric**).

If you have not already, select your Board and associated COM port. Upload the code to the board and set the [Arduino Serial Monitor](https://learn.sparkfun.com/tutorials/terminal-basics/all#arduino-serial-monitor-windows-mac-linux) to **115200** baud. The Arduino should begin outputting the sensor readings through the Arduino Serial Monitor and the Qwiic Alphanumeric display. For simplicity, we will only display PM2.5.

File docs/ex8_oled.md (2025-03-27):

This example shows how to read the BMV080 via Qwiic when the sensor is configured in duty cycle mode and outputs sensor data to a connected Qwiic OLED Display (specifically the 1.3", 128x64). You'll need a [Qwiic OLED Display](https://www.sparkfun.com/sparkfun-qwiic-oled-1-3in-128x64.html) connected to the Qwiic circuit to run this example.

Head to the example 8 from the Arduino IDE's menu (located in **File** **Examples** > **SparkFun BMV080 Arduino Library** > **Example_08_Demo_OLED**).

If you have not already, select your Board and associated COM port. Upload the code to the board and set the [Arduino Serial Monitor](https://learn.sparkfun.com/tutorials/terminal-basics/all#arduino-serial-monitor-windows-mac-linux) to **115200** baud. The Arduino should begin outputting the sensor readings through the Arduino Serial Monitor and the Qwiic OLED Display (1.3", 128x64).

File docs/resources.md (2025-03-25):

Now that you've successfully got your SparkFun Air Quality PM1/PM2.5/PM10 Sensor - BMV080 (Qwiic) up and running, it's time to incorporate it into your own project! For more information, check out the resources below:

* [Schematic (PDF)](../assets/board_files/SparkFun_Particulate_Matter_Sensor_Breakout_BMV080_v10_Schematic.pdf)
* [KiCad Files (ZIP)](../assets/board_files/SparkFun_Particulate_Matter_Sensor_Breakout_BMV080_v10.zip)
* [Board Dimensions (PNG)](../assets/img/SparkFun_Particulate_Matter_Sensor_Breakout_BMV080_Board_Dimensions.png)
* 3D Model
    * [Breakout Board (STEP)](../assets/3d_model/SparkFun_BMV080_v10_3D_model.step)
    * [Enclosure](./assets/3d_model/HMV080_Enclosure_Assembly.zip)
* Component Datasheets
    * [BMV080](./assets/component_documentation/bst-bmv080-ds000.pdf)
* Arduino Library
    * [SparkFun BMV080](https://github.com/sparkfun/SparkFun_BMV080_Arduino_Library)
    * [SparkFun Toolkit](https://github.com/sparkfun/SparkFun_Toolkit)
* [GitHub Hardware Repo](https://github.com/sparkfun/SparkFun_Particulate_Matter_Sensor_Breakout_BMV080/)

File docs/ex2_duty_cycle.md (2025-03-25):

This example shows how to read the BMV080 via Qwiic when the sensor is configured in duty cycle mode. Similar to the first example, the output will show the amount of particulate matter that is detected. However, it will show the readings every 20 seconds.

Head to the example 2 from the Arduino IDE's menu (located in **File** **Examples** > **SparkFun BMV080 Arduino Library** > **Example_02_DutyCycle**).

If you have not already, select your Board and associated COM port. Upload the code to the board and set the [Arduino Serial Monitor](https://learn.sparkfun.com/tutorials/terminal-basics/all#arduino-serial-monitor-windows-mac-linux) to **115200** baud. The Arduino should begin outputting the sensor readings every 20 seconds.

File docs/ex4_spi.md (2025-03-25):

!!! note
    Make sure to configure the board for SPI mode by adjusting the jumpers on the back of the board. You will also need to solder headers to the board and wire to your Arduino's SPI port.

This example shows how to read the BMV080 via SPI when the sensor is configured to continuous mode.

Head to the example 4 from the Arduino IDE's menu (located in **File** **Examples** > **SparkFun BMV080 Arduino Library** > **Example_04_SPI**).

If you have not already, select your Board and associated COM port. Upload the code to the board and set the [Arduino Serial Monitor](https://learn.sparkfun.com/tutorials/terminal-basics/all#arduino-serial-monitor-windows-mac-linux) to **115200** baud. The Arduino should begin outputting the sensor readings.

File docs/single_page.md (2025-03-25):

---
hide:
  - navigation
  - toc
icon: fontawesome/solid/scroll
---

# Quickstart Guide
--8<-- "./docs/quickstart.md"

# Introduction
--8<-- "./docs/introduction.md"

# Hardware Overview
--8<-- "./docs/hardware_overview.md"

# Hardware Hookup
--8<-- "./docs/hardware_assembly.md"

# Setting Up Arduino
--8<-- "./docs/setting_up_arduino.md"

# Arduino Example 1 &mdash; Basic Readings
--8<-- "./docs/ex1_basic_readings.md"

# Arduino Example 2 &mdash; Duty Cycle
--8<-- "./docs/ex2_duty_cycle.md"

# Arduino Example 3 &mdash; Interrupt
--8<-- "./docs/ex3_interrupt.md"

# Arduino Example 4 &mdash; SPI
--8<-- "./docs/ex4_spi.md"

# Arduino Example 5 &mdash; Parameters
--8<-- "./docs/ex5_parameters.md"

# Arduino Example 6 &mdash; Two Sensors
--8<-- "./docs/ex6_two_sensors.md"

# Arduino Example 7 &mdash; Qwiic Alphanumeric Display
--8<-- "./docs/ex7_alphanumeric.md"

# Arduino Example 8 &mdash; Qwiic OLED (1.3", 128x64)
--8<-- "./docs/ex8_oled.md"

# Troubleshooting
--8<-- "./docs/troubleshooting.md"

# Resources
--8<-- "./docs/resources.md"

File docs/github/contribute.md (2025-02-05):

# Contribute: Help Fix our Mistake!
Spot something wrong? Feel free to contribute our open-source design and documentation. 

## Improve our Documentation
All of this documentation can be modified by you! Please help us make it better.

* These pages are contained in the [`docs` folder of the SparkFun Qwiic Air Quality PM1/PM2.5/PM10 Sensor - BMV080 repository](https://github.com/sparkfun/SparkFun_Particulate_Matter_Sensor_Breakout_BMV080/tree/main/docs).

### Submit a Correction
1. Fork this repo
2. Add your corrections or improvements to the markdown file
3. File a pull request with your changes, and enjoy making the ~~words~~ ~~worlds~~ world a better place.
    * Once received, the documentation specialist will automatically be notified.
    * We will review your suggested improvements to make sure they are correct and fit within our documentation standards.

## Improve our Hardware Design
All of our designs are open-source! Please help us make it better.

* Our board design files are contained in the [`Hardware` folder of the SparkFun Qwiic Air Quality PM1/PM2.5/PM10 Sensor - BMV080 repository](https://github.com/sparkfun/SparkFun_Particulate_Matter_Sensor_Breakout_BMV080/tree/main/Hardware).

### Submit a Design Improvement
1. Fork this repo
2. Add your design improvements
3. File a pull request with your changes, and enjoy making the ~~words~~ ~~worlds~~ world a better place.
    * Once received, the engineer in charge of the original design will automatically be notified.
    * We will review your suggested improvements, if they are within our board design standards and meet our product design requirements, we will flag these changes for our next board revision. *(Please note, that even if your suggestion is accepted, these changes may not be immediate. We may have to cycle through our current product inventory first.)*

## Contributors
Let's provided some recognition to the contributors for this project!

GitHub Contributors Image
<br>


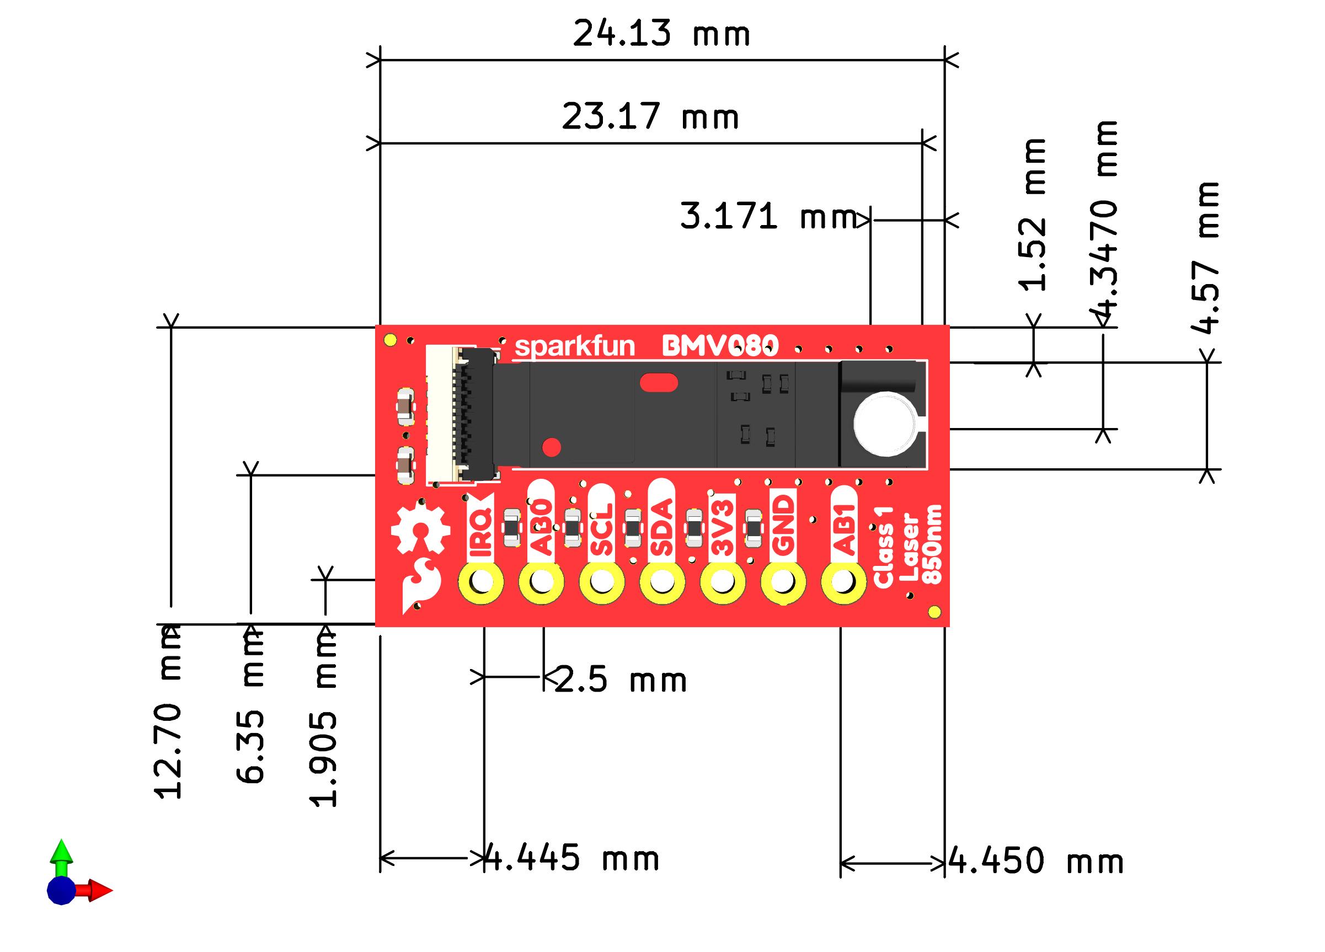
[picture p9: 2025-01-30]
docs/assets/3d_model/SparkFun_BMV080_v10_3D_image.jpg

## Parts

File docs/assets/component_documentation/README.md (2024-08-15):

SparkFun Documentation
=======================

This directory should include any necessary datasheets, example number crunching, etc.

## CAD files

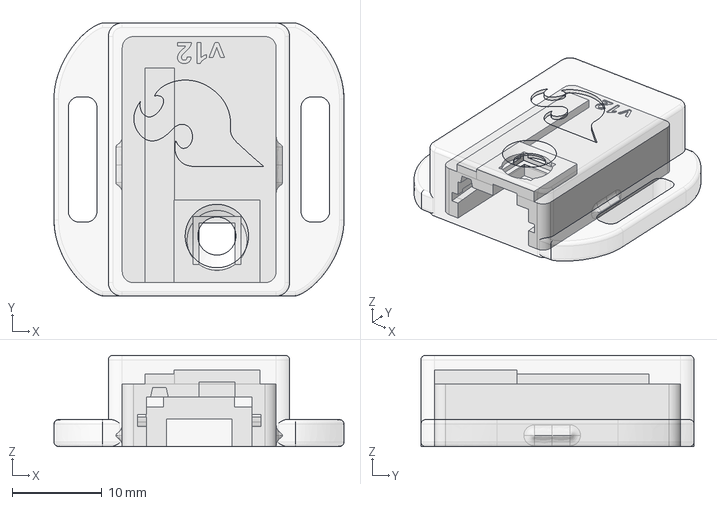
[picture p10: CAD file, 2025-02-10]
Enclosure/Enclosure_(FreeCAD)/HMV080_Enclosure_Assembly.FCStd
32.4 x 30.5 x 10.2 mm
HMV080_Enclosure_Outer_Shell_001
HMV080_Enclosure_Inner_Shell_001

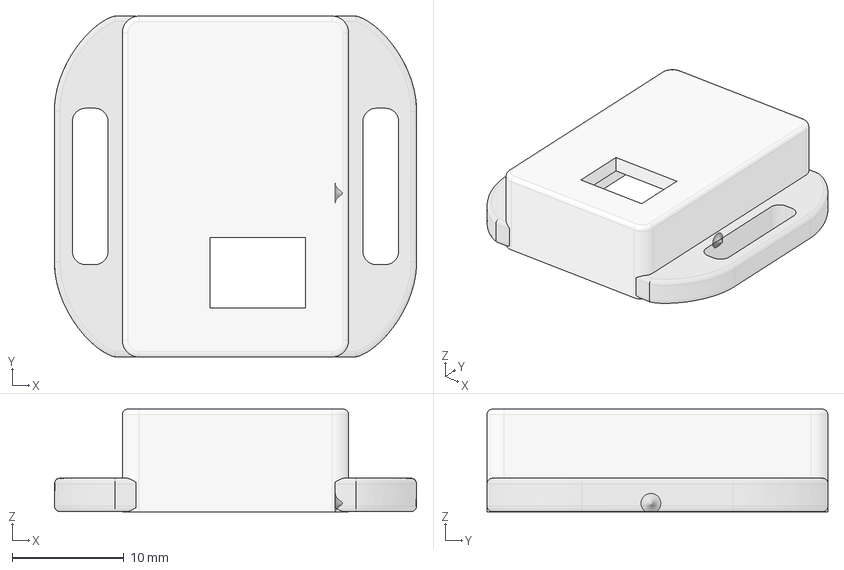
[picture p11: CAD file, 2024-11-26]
Enclosure/Demo_Mounting_Board/HMV080_Assembly_PCB_flex_V31a_OUTER_SHELL.step
32.4 x 30.5 x 9.20 mm
HMV080_Mounting_Flange_001
HMV080_Mounting_Flange_002
PCB_Stop_outer_shell

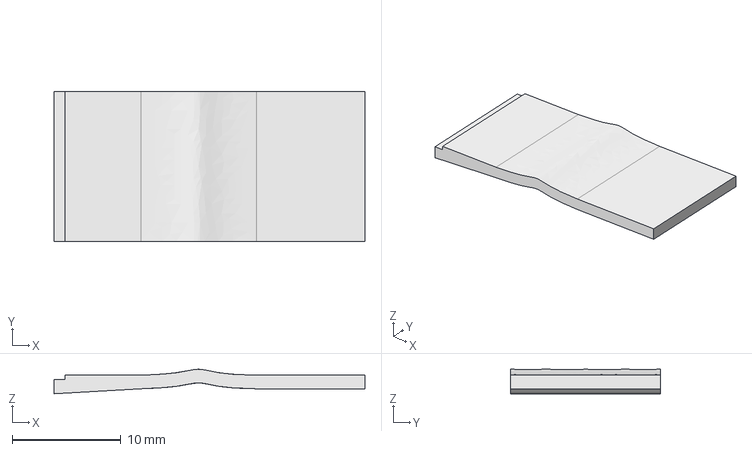
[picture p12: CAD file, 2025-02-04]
Enclosure/Enclosure_(FreeCAD)/HMV080_flex-slot-complete_channel.FCStd
28.6 x 13.8 x 2.26 mm

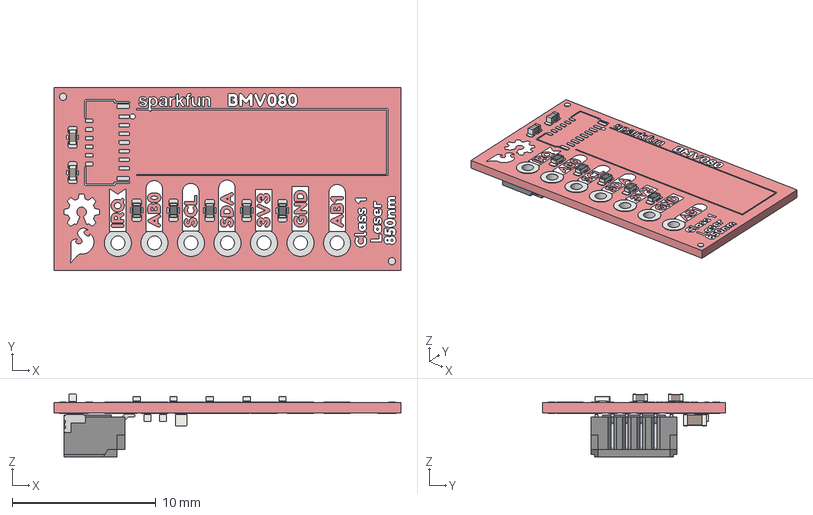
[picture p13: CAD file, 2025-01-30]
docs/assets/3d_model/SparkFun_BMV080_v10_3D_model.step
24.1 x 12.7 x 4.36 mm
R_0402_1005Metric x 5
C_0402_1005Metric x 4
Qwiic-Horizontal
C_0603_1608Metric
SparkFun_BMV080_copper
SparkFun_BMV080_pad
SparkFun_BMV080_silkscreen
SparkFun_BMV080_PCB

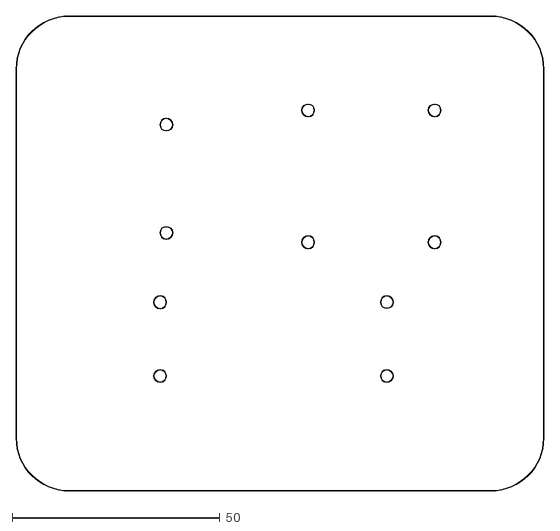
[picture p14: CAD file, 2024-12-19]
Enclosure/Demo_Mounting_Board/Demo_Mounting_Board-Body001Sketch001.dxf
127.0 x 114.3

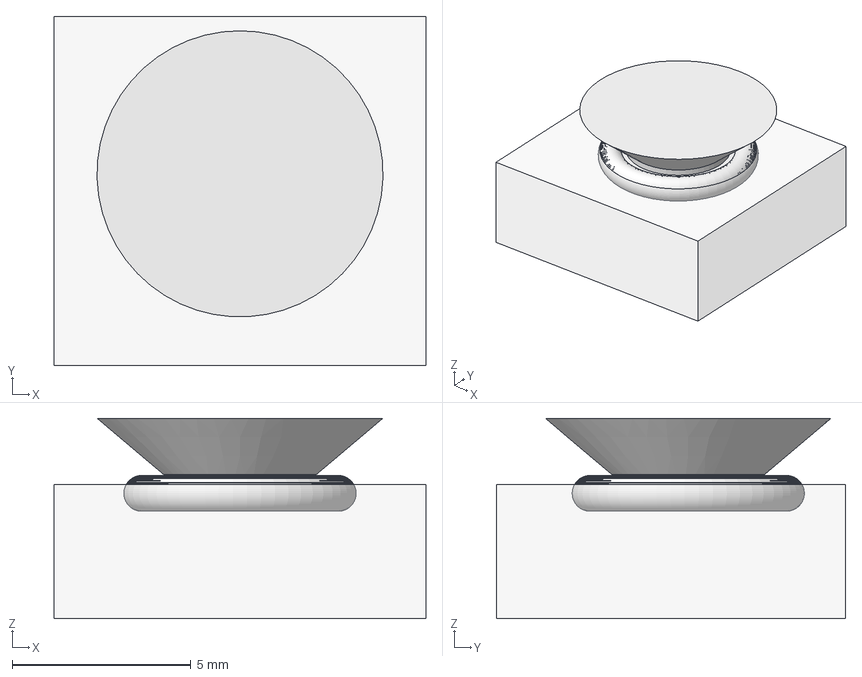
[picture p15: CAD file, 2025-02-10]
Enclosure/Enclosure_(FreeCAD)/sensor_opening_cut_OS.FCStd
10.4 x 9.76 x 5.61 mm
IS_mount_box_Cut
opening_revolve

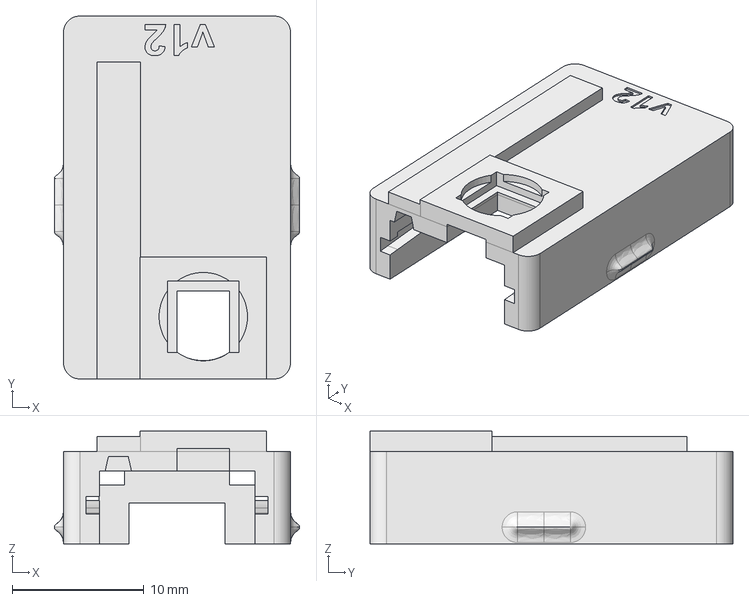
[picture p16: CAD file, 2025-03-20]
Enclosure/Enclosure_(STEP)/HMV080_Enclosure_Inner_Shell_v12.step
18.6 x 27.5 x 8.54 mm

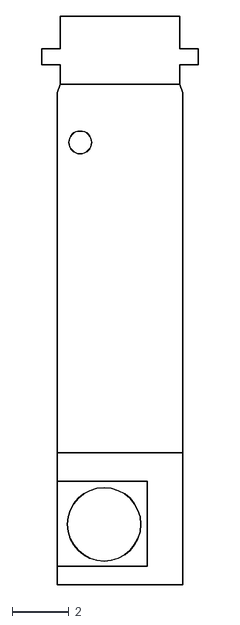
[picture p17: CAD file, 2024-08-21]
Hardware/HMV080_2D_Dimensional_top_down-Sketch.dxf
5.50 x 20.0

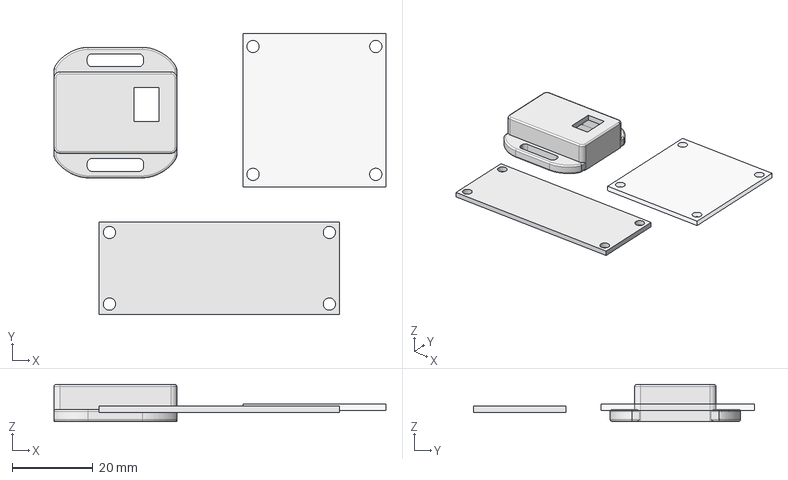
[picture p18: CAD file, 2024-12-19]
Enclosure/Demo_Mounting_Board/Demo_Mounting_Board.FCStd
82.4 x 69.7 x 9.20 mm
HMV080_Assembly_PCB_flex_V31a_OUTER_SHELL1_001
ESP32_ThingPlus_C_Dimensional_Mounting_001
SparkFun_Qwiic_OLED_13_Dimensional_Mounting_001

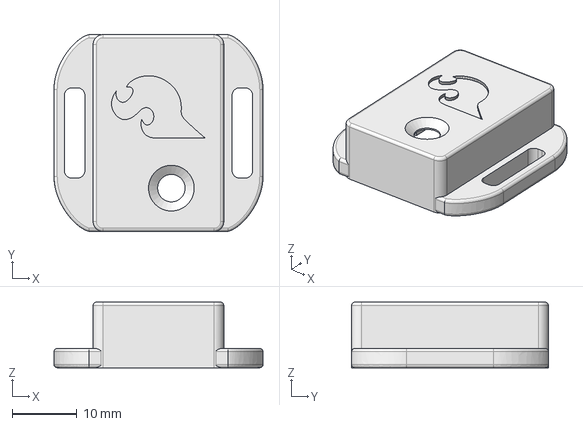
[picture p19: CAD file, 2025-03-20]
Enclosure/Enclosure_(STEP)/HMV080_Enclosure_Outer_Shell_v11.step
32.4 x 30.5 x 10.2 mm

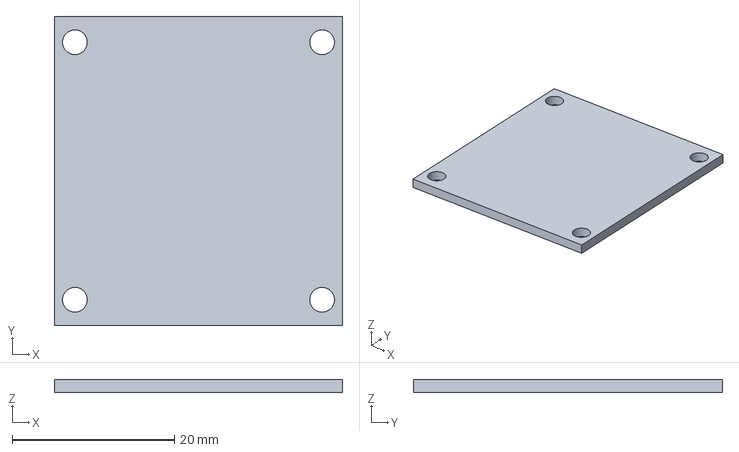
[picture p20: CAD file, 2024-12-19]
Enclosure/Demo_Mounting_Board/SparkFun_Qwiic_OLED_13_Dimensional_Mounting.FCStd
35.6 x 38.1 x 1.60 mm

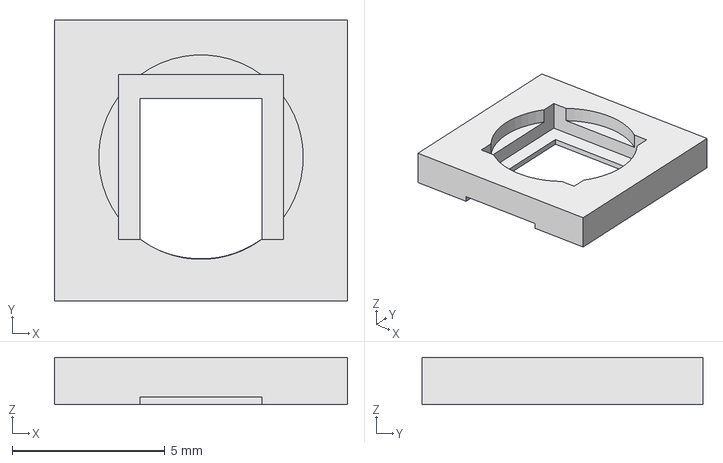
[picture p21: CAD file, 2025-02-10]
Enclosure/Enclosure_(FreeCAD)/o-ring_glass_mount_bottom.FCStd
9.60 x 9.22 x 1.55 mm

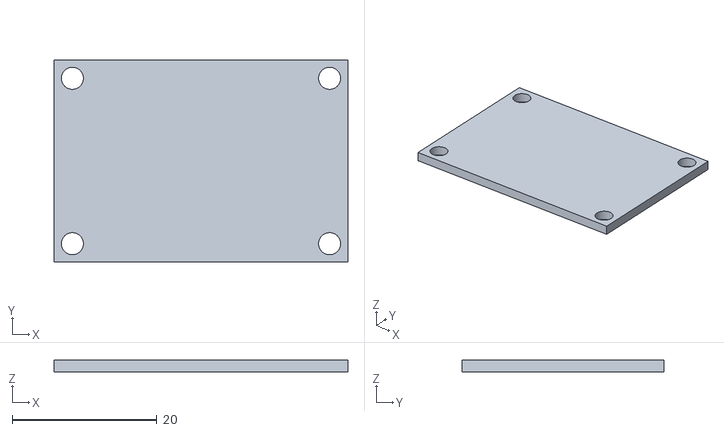
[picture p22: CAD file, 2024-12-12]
Enclosure/Demo_Mounting_Board/Alphanumeric_Dimensional_Mounting_001 (Meshed).stl
40.6 x 27.9 x 1.60

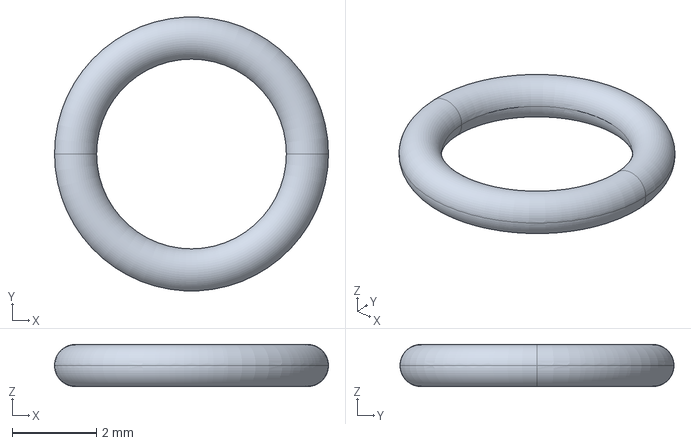
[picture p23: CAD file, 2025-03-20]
Enclosure/Enclosure_(STEP)/HMV080_Enclosure_O-ring.step
6.50 x 6.49 x 1.00 mm

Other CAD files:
Enclosure/Enclosure_(STL)/BMV080_Enclosure_Part_A_Inside_Shell_V12.stl
Enclosure/Enclosure_(STL)/BMV080_Enclosure_Part_B_Outside_Shell_V11.stl
Enclosure/Enclosure_(FreeCAD)/HMV080_Enclosure_Outer_Shell.FCStd
Enclosure/Demo_Mounting_Board/Alphanumeric_Dimensional_Mounting.FCStd
Enclosure/Demo_Mounting_Board/ESP32_ThingPlus_C_Dimensional_Mounting.FCStd
Enclosure/Demo_Mounting_Board/ESP32_ThingPlus_C_Dimensional_Mounting_001 (Meshed).stl
Enclosure/Demo_Mounting_Board/HMV080_Demo_Mounting_Board_v01.dxf
Enclosure/Demo_Mounting_Board/HMV080_Demo_Mounting_Board_v02.dxf
Enclosure/Demo_Mounting_Board/Qwiic_Alphanumeric_Display.dxf
Enclosure/Enclosure_(FreeCAD)/91772A106_Passivated 18-8 Stainless Steel Pan Head Phillips Screw.STEP
Enclosure/Enclosure_(FreeCAD)/BMV080_Sensor_and_FPC_Connector.step
Enclosure/Enclosure_(FreeCAD)/FPC_0.3mm-13_MOLEX_503566-1302.step
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

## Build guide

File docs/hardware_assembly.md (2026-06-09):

### Connecting via Qwiic

By default, the sensor can be read through I<sup>2</sup>C. Connect a Qwiic cable between the SparkFun Qwiic Air Quality Sensor and your microcontroller. Then connect a compatible USB cable between the microcontroller and your computer's USB port.

Photo of completed Qwiic assembly

### Removing the BMV080 from the enclosure

The Air Quality PM1/PM2.5/PM10 Sensor - BMV080 (Qwiic) comes housed in an enclosure to help protect the sensor during handling and installation. The enclosure does expose the solder jumpers and PTH pins for users to access while the board is inside the enclosure. While it is possible to access these parts of the board, we recommend removing the breakout from the enclosure prior to working with either the solder jumpers or PTH pins. 

We strongly recommend putting on Latex or Nitrile gloves (and **not** following our bad example in the photos below) before removing the board from the enclosure. Also, make sure to perform these steps on a **clean** and **flat** surface. Whether or not you decide to use gloves, do your best to avoid touching the enclosure's glass sensor cover and **do not** touch the bare sensor or any of the passive components (resistors/capacitors) near it:

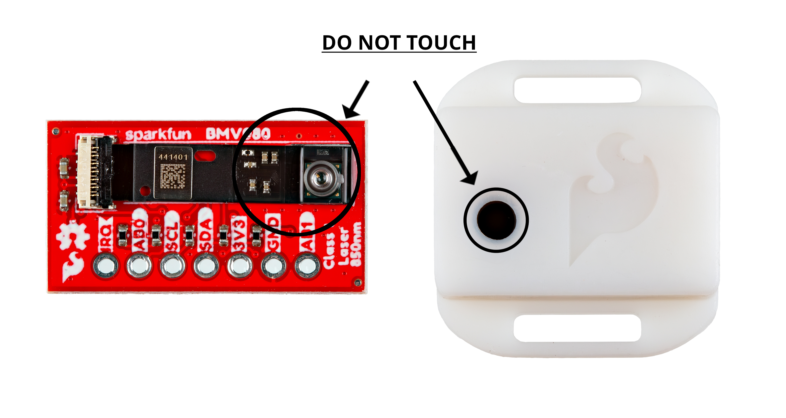
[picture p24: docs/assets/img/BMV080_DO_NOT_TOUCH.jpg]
Photo showing areas to avoid touching while handling the BMV080


Start by identifying the two slots on either side of the enclosure. Next, carefully slide a precision flathead screwdriver or similar precise tool into one of the slots and gently wedge it under the tab. Rock the precision flathead's handle toward the mounting hole so the tab pops out.

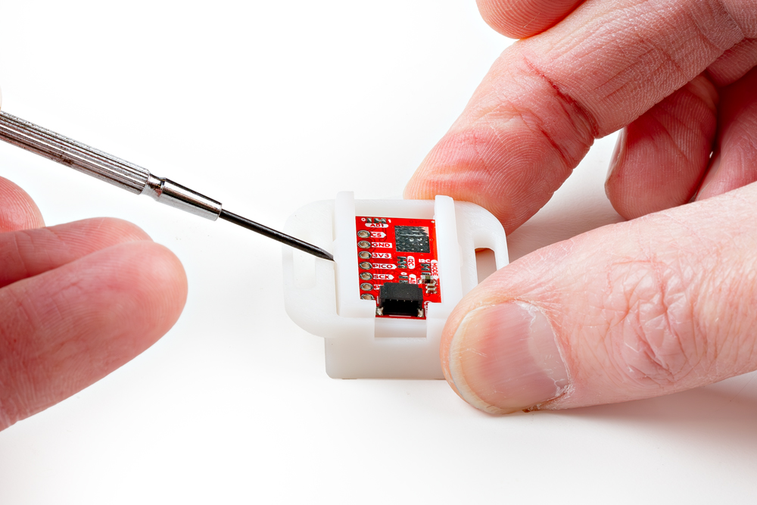
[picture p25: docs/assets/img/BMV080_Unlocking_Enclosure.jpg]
Photo showing using a precision screwdriver to unlock the tab holding the two enclosure pieces together.


Repeat this step on the other side to "unlock" the two pieces of the enclosure, then carefully remove the outer shell of the enclosure.

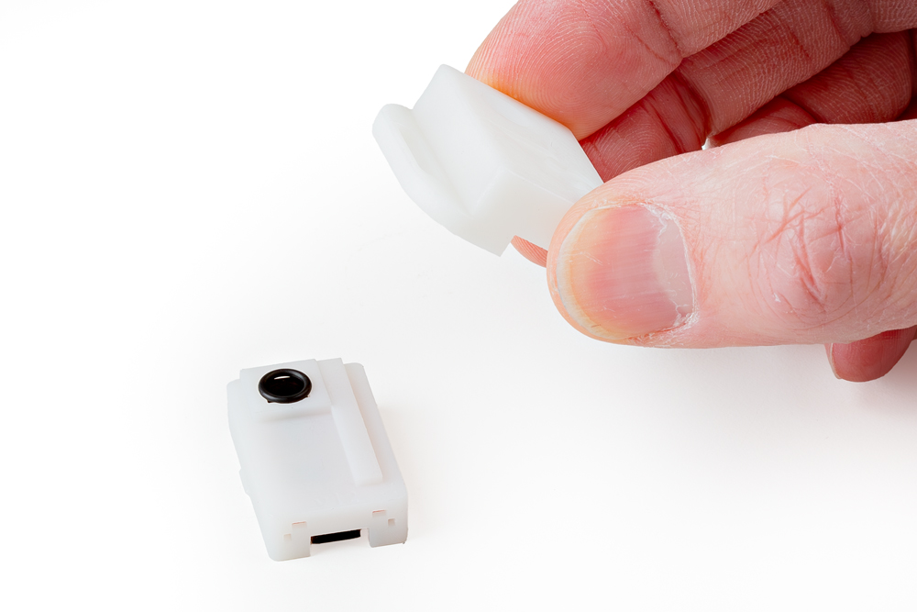
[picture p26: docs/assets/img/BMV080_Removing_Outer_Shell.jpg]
Photo showing separation of the two pieces of the sensor enclosure.


Next, identify the rubber O-ring and lens cover (beneath the O-ring) covering the BMV080 aperture. Using tweezers, first remove the O-ring and then the lens cover. Make sure to place them on a clean surface to avoid contaminating them with dust or other substances:

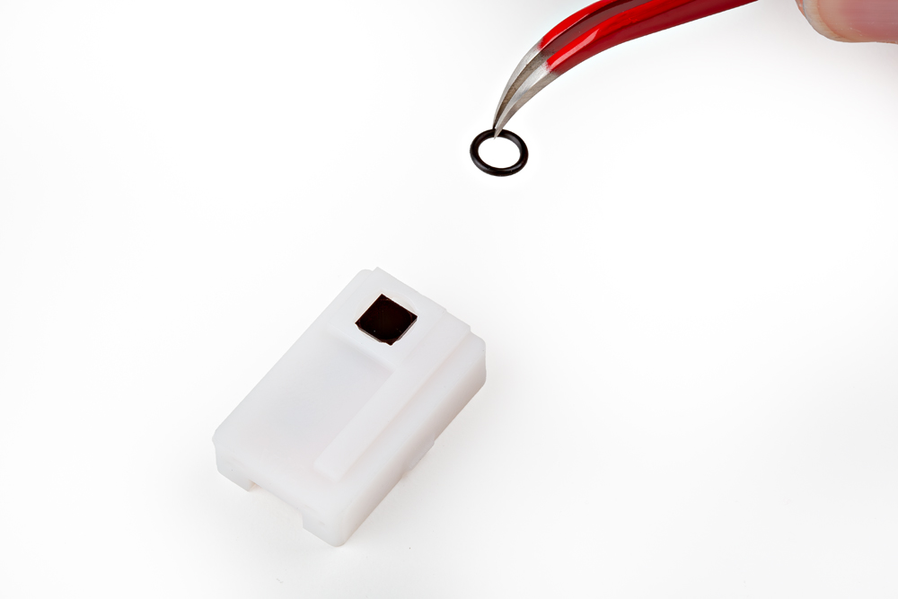
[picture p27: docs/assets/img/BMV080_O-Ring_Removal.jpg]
Photo showing removing the O-ring with tweezers.


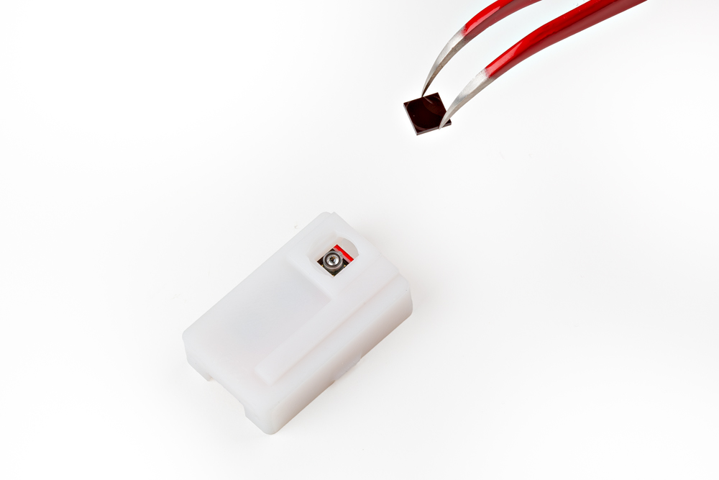
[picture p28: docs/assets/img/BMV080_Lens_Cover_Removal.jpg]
Photo showing removing the lense cover with tweezers.


With the O-ring and lens cover removed, the assembly should look like the photo below:

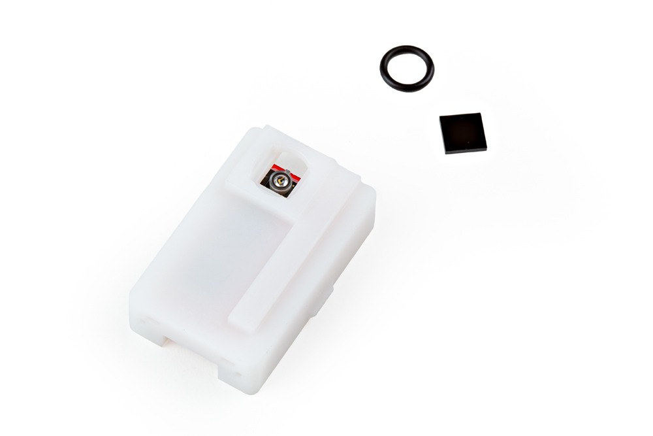
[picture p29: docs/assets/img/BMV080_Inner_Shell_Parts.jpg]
Photo showing O-ring and lens cover removed next to the inner shell.


The inner shell of the enclosure has a small notch to lock the breakout board into place inside. Using either your fingertip or tweezers, gently press down on the edge of the breakout board while pressing from the other side to slide the board out from the inner shell.

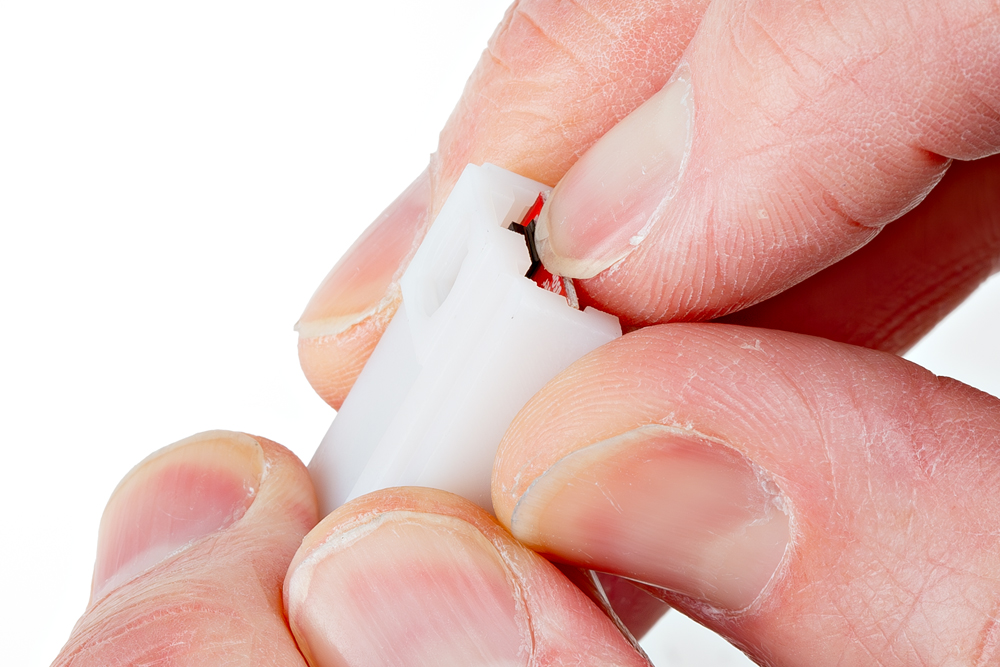
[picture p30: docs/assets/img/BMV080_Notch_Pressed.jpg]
Photo showing breakout board pressed down to bypass the notch in the inner enclosure.


Slide the sensor out from the inner shell's slot while taking care to avoid touching the BMV080 sensor and passive components on the sensor's ribbon cable. 

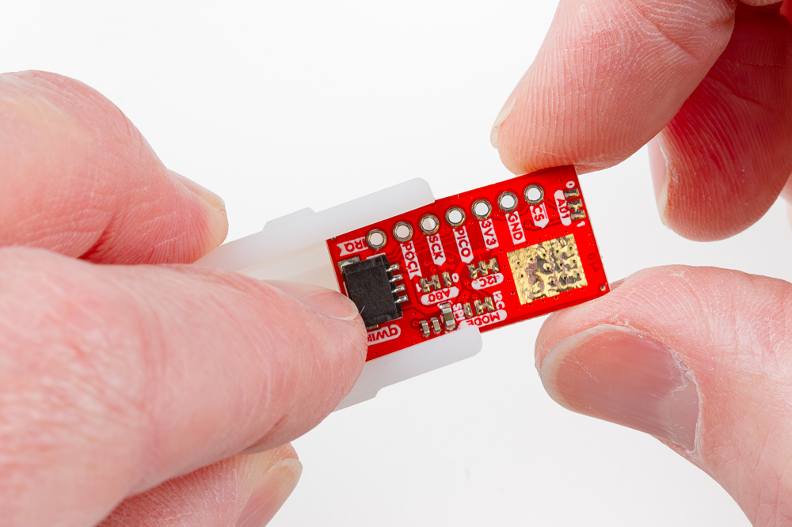
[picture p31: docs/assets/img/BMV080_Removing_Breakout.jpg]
Photo showing the breakout board being removed from the inner enclosure.


Now that the breakout board is out of the enclosure we can solder to the board and adjust the solder jumpers. If using male header pins, solder the short end from the top side of the board so that you can access the longer mating pins from the bottom side. If you're soldering wires, make sure to trim the leads as short as possible to avoid obstructing the board from sliding back into the enclosure. After soldering, carefully clean the solder joints to remove any flux residue left on the board using isopropyl alcohol and a Q-tip or other gentle cleaning tool.

!!! note
    When soldering make sure to not add too much solder. Excess solder can obstruct the breakout board from sliding back into the inner shell. For users soldering header pins, ensure that the header's plastic spacer is flush against the breakout board and not at an angle. For users soldering wire, ensure that the stripped wire is short.

### Reassembling the Enclosure

Once we're done modifying the breakout board we'll want to place the sensor back in the enclosure. This section goes over how to reassemble the parts but essentially we're just working backward through the previous steps.

Start by sliding the BMV080 breakout board back into the inner shell until it "clicks" back into place once it is past the notch. Make sure the BMV080 sensor and the Qwiic connector align with their respective apertures in the inner shell:

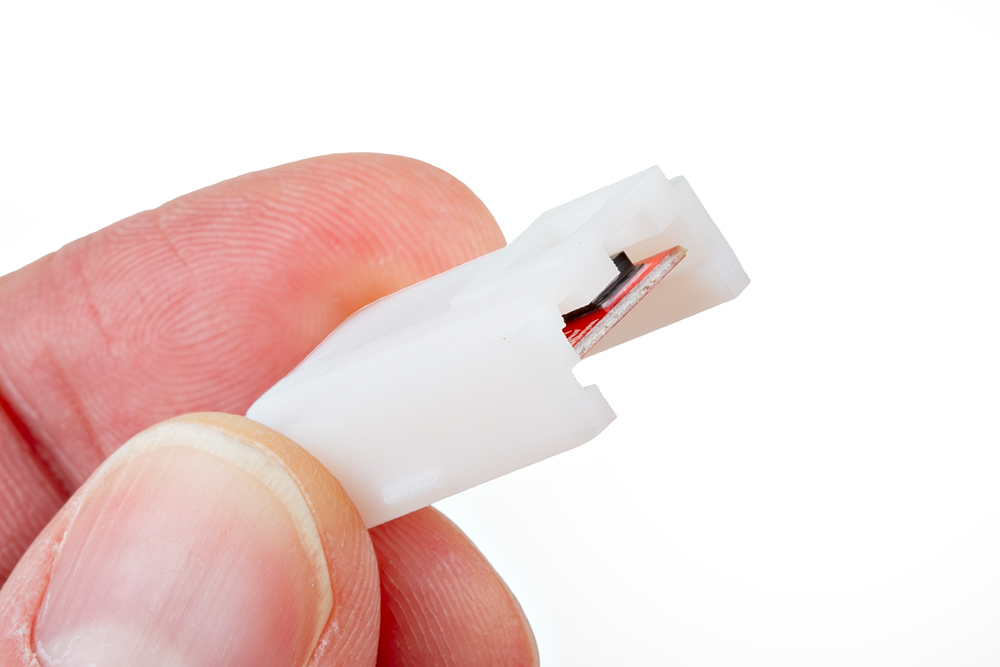
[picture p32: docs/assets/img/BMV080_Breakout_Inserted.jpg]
Photo showing BMV080 breakout secured back into the inner shell.


Turn the enclosure over on a clean, flat surface. Using tweezers, place the lens cover over the hole where the BMV080's sensor is located. Then place the o-ring over lens cover. Ensure that the parts are in their respective square and circular slots.

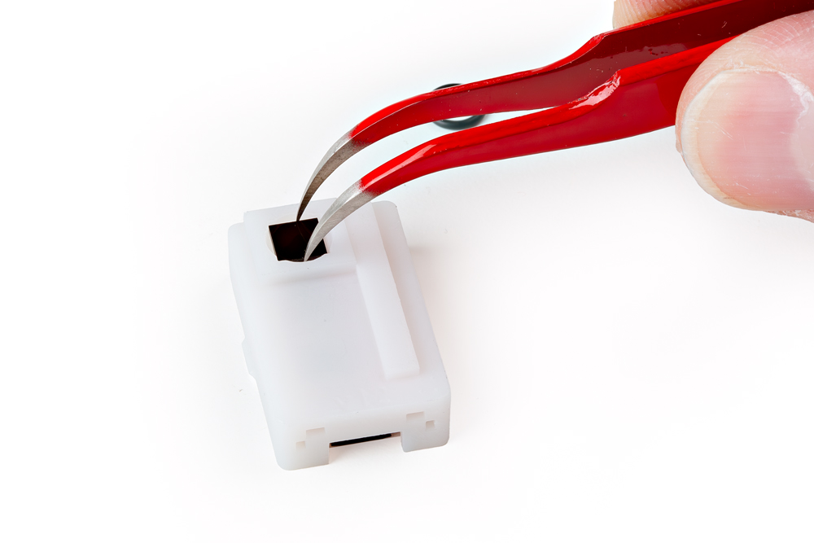
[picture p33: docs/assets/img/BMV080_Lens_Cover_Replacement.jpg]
Photo showing lens cover being placed back onto inner shell.


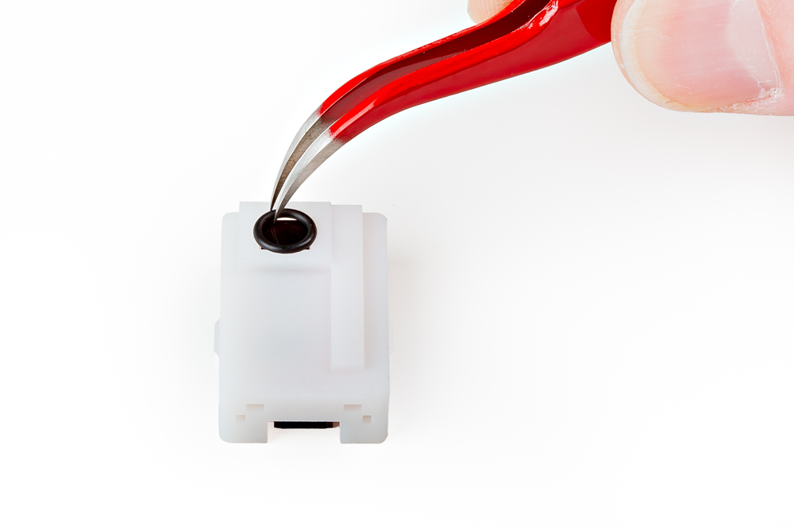
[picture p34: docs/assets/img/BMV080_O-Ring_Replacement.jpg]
Photo showing o-ring being placed back onto inner shell.


Now take the outer shell and place it back onto the inner shell making sure to align the apertures for the BMV080 and Qwiic connectors. Push down until you hear the tabs pop in.

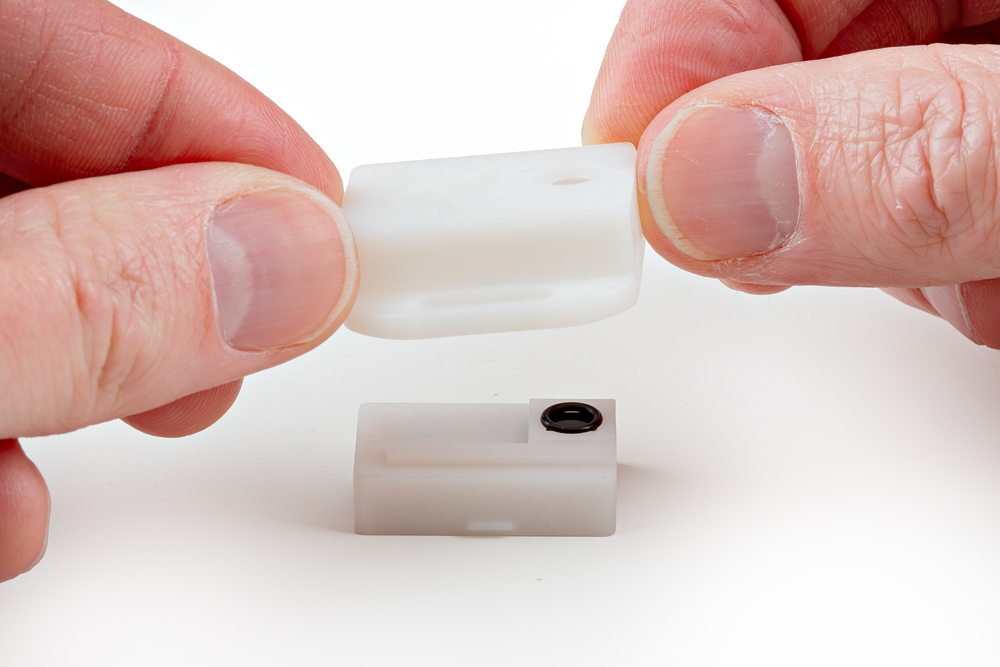
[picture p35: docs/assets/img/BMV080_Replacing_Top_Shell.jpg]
Photo showing outer shell being placed back on top of inner shell


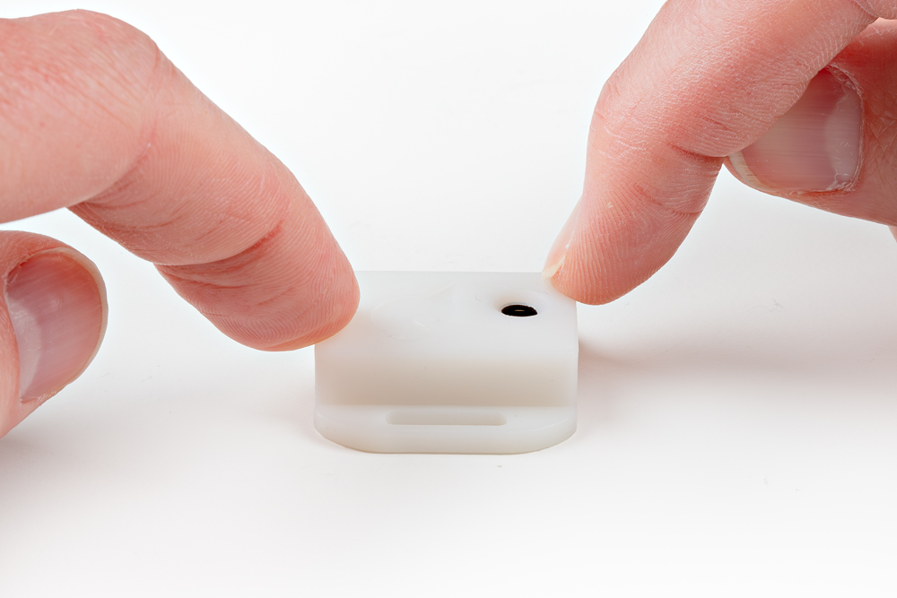
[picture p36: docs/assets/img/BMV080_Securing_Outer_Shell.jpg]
Photo showing pressing down to secure outer and inner shell together.


### Connecting via PTH

!!! note
    When soldering directly to the PTHs, you will need to be careful of the 3D printed enclosure! You will want to carefully remove the board from the enclosure when soldering.

For temporary connections to the PTHs, you could use IC hooks to test out the pins. However, you'll need to solder headers or wires of your choice to the board for a secure connection. You can choose between a combination of [header pins and jumper wires](https://learn.sparkfun.com/tutorials/how-to-solder-through-hole-soldering/all), or [stripping wire and soldering the wire](https://learn.sparkfun.com/tutorials/working-with-wire/all) directly to the board.

<div class="grid cards col-2" markdown>

-   <a href="https://learn.sparkfun.com/tutorials/how-to-solder-through-hole-soldering/all">
      <figure markdown>
        How to Solder: Through Hole Soldering
      </figure>
    </a>

    ---

    <a href="https://learn.sparkfun.com/tutorials/how-to-solder-through-hole-soldering/all">
      <b>How to Solder: Through Hole Soldering</b>
    </a>
<!-- ----------WHITE SPACE BETWEEN GRID CARDS---------- -->

-   <a href="https://learn.sparkfun.com/tutorials/working-with-wire/all">
      <figure markdown>
        Working with Wire
      </figure>
    </a>

    ---

    <a href="https://learn.sparkfun.com/tutorials/working-with-wire/all">
      <b>Working with Wire</b>
    </a>
<!-- ----------WHITE SPACE BETWEEN GRID CARDS---------- -->
</div>

### Interrupt

The following table shows the connection that is required between an ESP32 and the SparkFUn Qwiic Air Quality Sensor when using I<sup>2</sup>C as the communication interface with interrupts.

<div style="text-align: center;">
    <table>
        <tr>
            <th style="text-align: center; border: solid 1px #cccccc;">ESP32 Pinout<br />(i.e. IoT RedBoard - ESP32, ESP32 Thing Plus C, etc.)
            </th>
            <th style="text-align: center; border: solid 1px #cccccc;">SparkFun Qwiic Air Quality Sensor<br />BMV080
            </th>
        </tr>
        <tr>
            <td style="text-align: center; border: solid 1px #cccccc;" bgcolor="#DDDDDD"><font color="#000000">GND</font>
            </td>
            <td style="text-align: center; border: solid 1px #cccccc;" bgcolor="#DDDDDD"><font color="#000000">GND</font>
            </td>
        </tr>
        <tr>
            <td style="text-align: center; border: solid 1px #cccccc;" bgcolor="#f2dede"><font color="#000000">3.3V</font>
            </td>
            <td style="text-align: center; border: solid 1px #cccccc;" bgcolor="#f2dede"><font color="#000000">3V3</font>
            </td>
        </tr>
        <tr>        
            <td style="text-align: center; border: solid 1px #cccccc;" bgcolor="#cce5ff"><font color="#000000">SDA</font>
            </td>
            <td style="text-align: center; border: solid 1px #cccccc;" bgcolor="#cce5ff"><font color="#000000">SDA (PICO)</font>
            </td>
        </tr>
        <tr>
            <td style="text-align: center; border: solid 1px #cccccc;" bgcolor="#fff3cd"><font color="#000000">SCL</font>
            <td style="text-align: center; border: solid 1px #cccccc;" bgcolor="#fff3cd"><font color="#000000">SCL (SCK)</font>
            </td>
        </tr>
        <tr>
            <td style="text-align: center; border: solid 1px #cccccc;" bgcolor="#d4edda"><font color="#000000">14</font>
            </td>
            <td style="text-align: center; border: solid 1px #cccccc;" bgcolor="#d4edda"><font color="#000000">IRQ</font>
            </td>
        </tr>
    </table>
</div>

### SPI

The following tables shows the connection that is required between between an ESP32 and the SparkFun Qwiic Air Quality Sensor when using SPI as the communication interface. You will need to cut the MODE jumper between the center pad and the pad labeled as I2C. Then add solder between the center pad and the pad labeled as SPI. Make sure to also leave the AB0 jumper open (i.e. both sides of the jumper are not connected).

<div style="text-align: center;">
    <table>
        <tr>
            <th style="text-align: center; border: solid 1px #cccccc;">ESP32 Pinout<br />(i.e. IoT RedBoard - ESP32, ESP32 Thing Plus C, etc.)
            </th>
            <th style="text-align: center; border: solid 1px #cccccc;">SparkFun Qwiic Air Quality Sensor<br />BMV080
            </th>
        </tr>
        <tr>
            <td style="text-align: center; border: solid 1px #cccccc;" bgcolor="#DDDDDD"><font color="#000000">GND</font>
            </td>
            <td style="text-align: center; border: solid 1px #cccccc;" bgcolor="#DDDDDD"><font color="#000000">GND</font>
            </td>
        </tr>
        <tr>
            <td style="text-align: center; border: solid 1px #cccccc;" bgcolor="#f2dede"><font color="#000000">3.3V</font>
            </td>
            <td style="text-align: center; border: solid 1px #cccccc;" bgcolor="#f2dede"><font color="#000000">3V3</font>
            </td>
        </tr>
        <tr>        
            <td style="text-align: center; border: solid 1px #cccccc;" bgcolor="#cce5ff"><font color="#000000">PICO</font>
            </td>
            <td style="text-align: center; border: solid 1px #cccccc;" bgcolor="#cce5ff"><font color="#000000">PICO (SDA)</font>
            </td>
        </tr>
        <tr>
            <td style="text-align: center; border: solid 1px #cccccc;" bgcolor="#d4edda"><font color="#000000">POCI</font>
            </td>
            <td style="text-align: center; border: solid 1px #cccccc;" bgcolor="#d4edda"><font color="#000000">POCI (AB0)</font>
            </td>
        </tr>
        <tr>
            <td style="text-align: center; border: solid 1px #cccccc;" bgcolor="#fff3cd"><font color="#000000">SCK</font>
            <td style="text-align: center; border: solid 1px #cccccc;" bgcolor="#fff3cd"><font color="#000000">SCK (SCL)</font>
            </td>
        </tr>
        <tr>
            <td style="text-align: center; border: solid 1px #cccccc;" bgcolor="#f2dede"><font color="#000000">CS</font>
            </td>
            <td style="text-align: center; border: solid 1px #cccccc;" bgcolor="#f2dede"><font color="#000000">CS (AB1)</font>
            </td>
        </tr>
    </table>
</div>

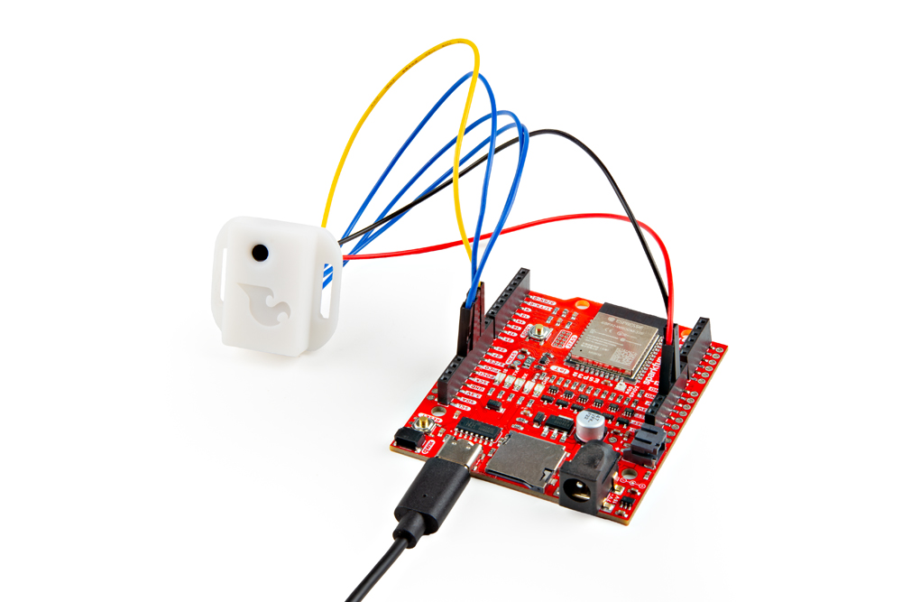
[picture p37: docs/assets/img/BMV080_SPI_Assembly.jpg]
Photo of SPI assembly with IoT RedBoard - ESP32


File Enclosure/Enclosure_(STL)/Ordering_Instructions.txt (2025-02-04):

Ordering Instructions:

3D Technology SLA(Resin)
Material: LEDO 6060 Resin
Colors: Natural White
Surface Finish: Sanding-General Sanding
Product Desc: Plastic Enclosure

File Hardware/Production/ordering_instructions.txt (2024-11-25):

Ordering Instructions:
Panel dimensions: 161.03 x 132.05 mm.
Material: TG155
Solder Mask: Red
Silkscreen Color: White
Layers: 2
Finish: HASL Lead-free
Thickness: 0.8mm
Copper Weight: 1oz
Minimum track width: 0.20mm (7.87mil)
Minimum via drill: 0.30mm (11.81mil)

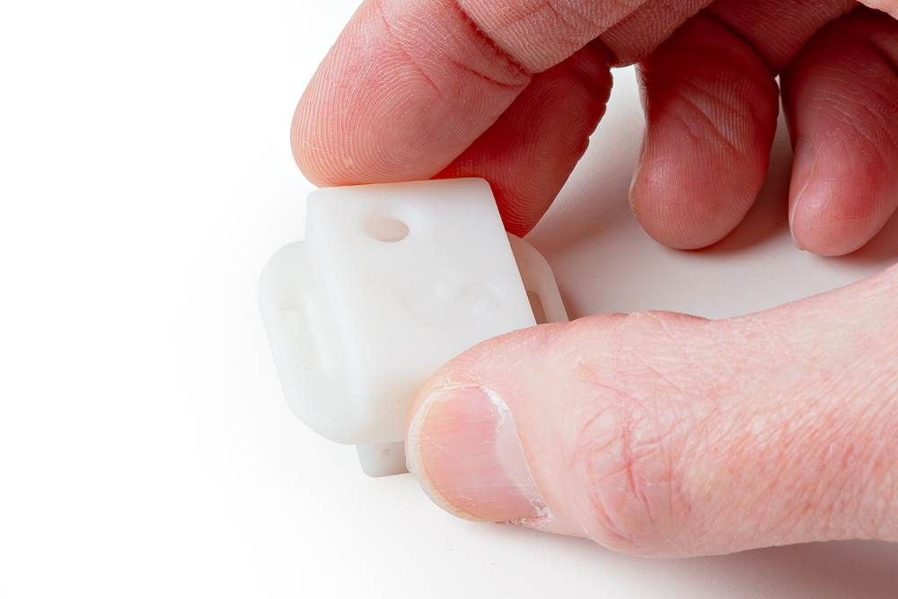
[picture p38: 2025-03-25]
docs/assets/img/6554-BMV-Particulate-Matter-Sensor-Assembly-5.jpg

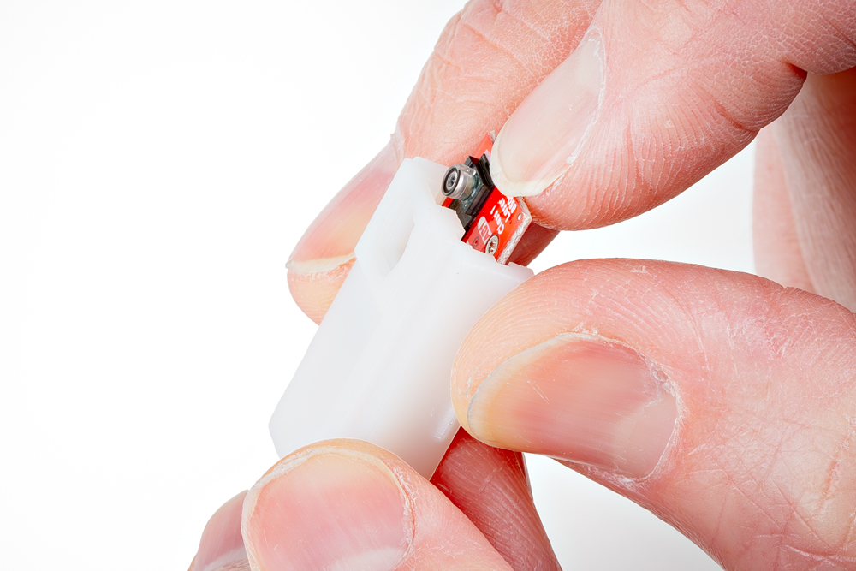
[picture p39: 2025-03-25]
docs/assets/img/6554-BMV-Particulate-Matter-Sensor-Assembly-13.jpg

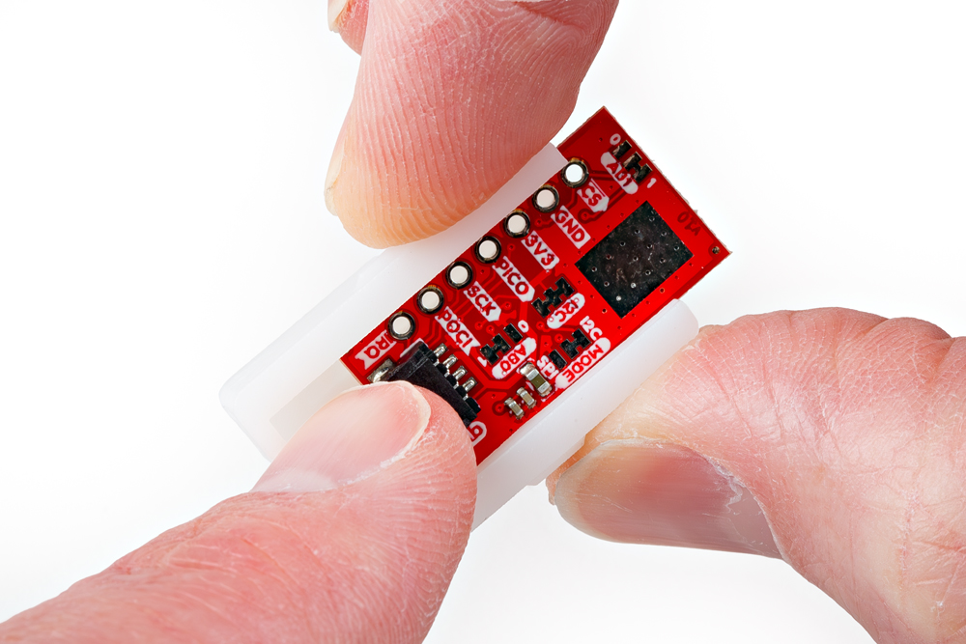
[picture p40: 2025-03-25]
docs/assets/img/6554-BMV-Particulate-Matter-Sensor-Assembly-12.jpg

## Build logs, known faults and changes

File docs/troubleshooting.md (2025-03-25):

### Sensor Handling & Care

The BMV080's sensing apparatus is exceptionally sensitive and can be obstructed by small particles of dust along with any other substance present on either the sensor itself or the enclosure's protective lense such as oil from your fingers. Be very careful when handling the sensor to not touch the sensing area even when in the enclosure.

If the sensor reports any "obstruction" carefully clean the sensor using compressed air (recommended) or, if absolutely necessary, a clean, non-abrasive tissue.

### General Troubleshooting Help

!!! note
    <span class="glyphicon glyphicon-question-sign" aria-hidden="true"></span>
        <strong> Not working as expected and need help? </strong> <br /><br />

    If you need technical assistance and more information on a product that is not working as you expected, we recommend heading on over to the <a href="https://www.sparkfun.com/technical_assistance">SparkFun Technical Assistance</a> page for some initial troubleshooting. <br /><br />

    <div style="text-align: center"><a href="https://www.sparkfun.com/technical_assistance" target="sfe_technical_assistance" class="md-button">SparkFun Technical Assistance Page</a></div>

    If you don't find what you need there, the <a href="https://community.sparkfun.com/">SparkFun Forums</a> are a great place to find and ask for help. If this is your first visit, you'll need to create a forum account to search product forums and post questions.<br /><br />

    <div style="text-align: center"><a href="https://community.sparkfun.com/" class="md-button md-button--primary">Log Into SparkFun Forums</a></div>

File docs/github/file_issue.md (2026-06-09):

# Did we make a mistake?

Spot something wrong? Please let us know. 

!!! attention
    This is not where customers should seek assistance on a product. If you require technical assistance or have questions about a product that is not working as expected, please head over to the [SparkFun Technical Assistance](https://www.sparkfun.com/technical_assistance) page for some initial troubleshooting.
    
    [SparkFun Technical Assistance Page](https://www.sparkfun.com/technical_assistance){ .md-button .md-button--primary }

    If you can't find what you need there, you'll need a [Forum Account](https://forum.sparkfun.com/ucp.php?mode=register) to search product forums and post questions.

## Discrepancies in the Documentation

All of this documentation can be modified by you! Please help us make it better.

* The documentation files for these pages are contained in the [`docs` folder of the SparkFun Qwiic Air Quality PM1/PM2.5/PM10 Sensor - BMV080 repository](https://github.com/sparkfun/SparkFun_Particulate_Matter_Sensor_Breakout_BMV080/tree/main/docs).

### Spot something wrong?
If a section of the documentation is incorrect, please [open an issue](https://github.com/sparkfun/SparkFun_Particulate_Matter_Sensor_Breakout_BMV080/issues) and let us know.

### Do you have a suggested correction?
1. With a GitHub account, fork this repo
2. Add your correction(s) or improvement(s) to the markdown file(s)
3. File a pull request with your changes, and enjoy making the ~~words~~ ~~worlds~~ world a better place.
    * Once received, the documentation specialist will automatically be notified.
    * We will review your suggested improvement(s) to make sure they are correct and fit within our documentation standards.

## Problems in the Hardware Design

All of our designs are open-source! Please help us make it better.

* Our board design files are contained in the [`Hardware` folder of the SparkFun Qwiic Air Quality PM1/PM2.5/PM10 Sensor - BMV080 repository](https://github.com/sparkfun/SparkFun_Particulate_Matter_Sensor_Breakout_BMV080/tree/main/Hardware).

### Does something not make sense?
If part of the design is confusing, please [open an issue](https://github.com/sparkfun/SparkFun_Particulate_Matter_Sensor_Breakout_BMV080/issues) and let us know.

### Did we forget to include an important function of the board?
* Please keep in mind that we may intentionally exclude certain functions of the board to meet our product design requirements. *(For example, our Qwiic Micro boards are intended to fit on a small board layout and only use I<sup>2</sup>C communication; therefore, we may not have the SPI and interrupt pins available for users.)*
* If part of the board's functionality is missing, please [open an issue](https://github.com/sparkfun/SparkFun_Particulate_Matter_Sensor_Breakout_BMV080/issues) and file a feature request.

### Do you wish to contribute directly to improving the board design?
1. With a GitHub account, Fork this repo
2. Add your design improvement(s)
3. File a pull request with your changes, and enjoy making the ~~words~~ ~~worlds~~ world a better place.
    * Once received, the engineer in charge of the original design will automatically be notified.
    * We will review your suggested improvement(s), if they are within our board design standards and meet our product design requirements, we will flag these changes for our next board revision. *(Please note, that even if your suggestion is accepted, these changes may not be immediate. We may have to cycle through our current product inventory first.)*

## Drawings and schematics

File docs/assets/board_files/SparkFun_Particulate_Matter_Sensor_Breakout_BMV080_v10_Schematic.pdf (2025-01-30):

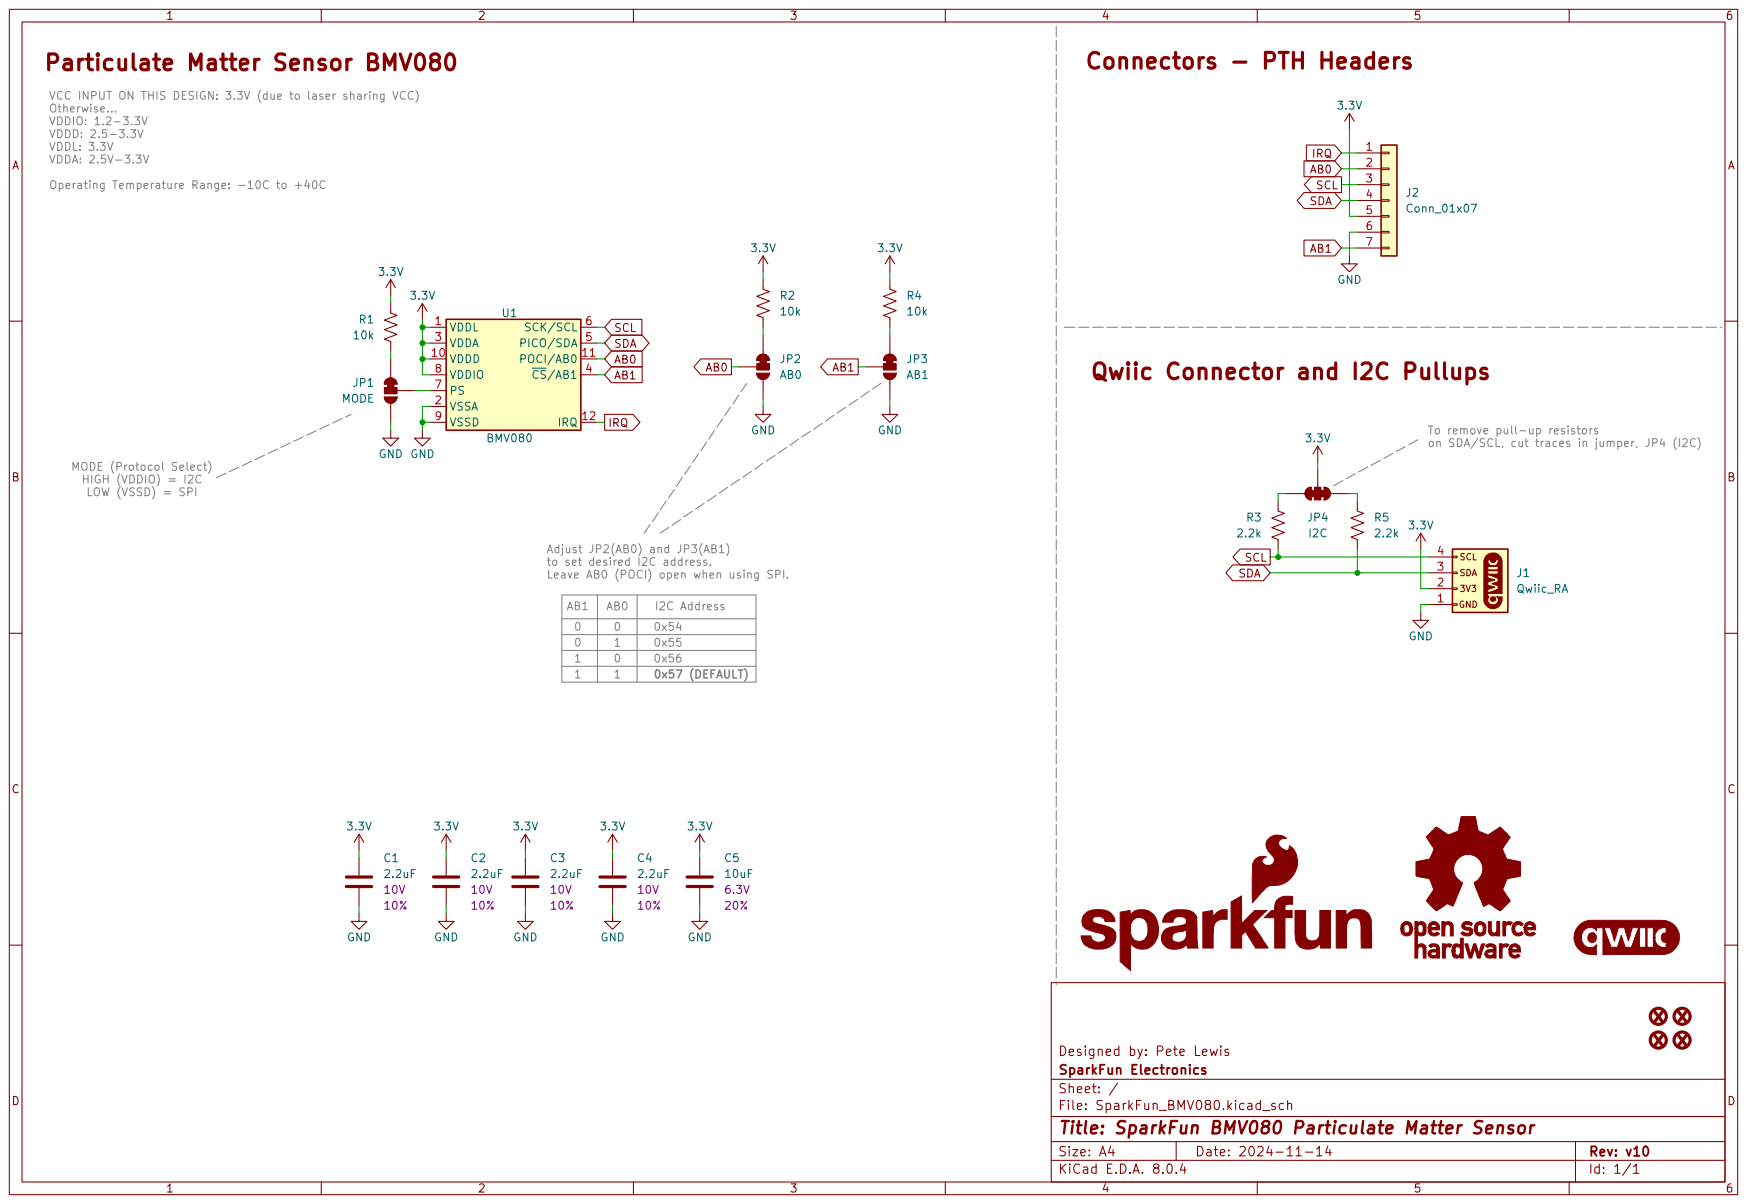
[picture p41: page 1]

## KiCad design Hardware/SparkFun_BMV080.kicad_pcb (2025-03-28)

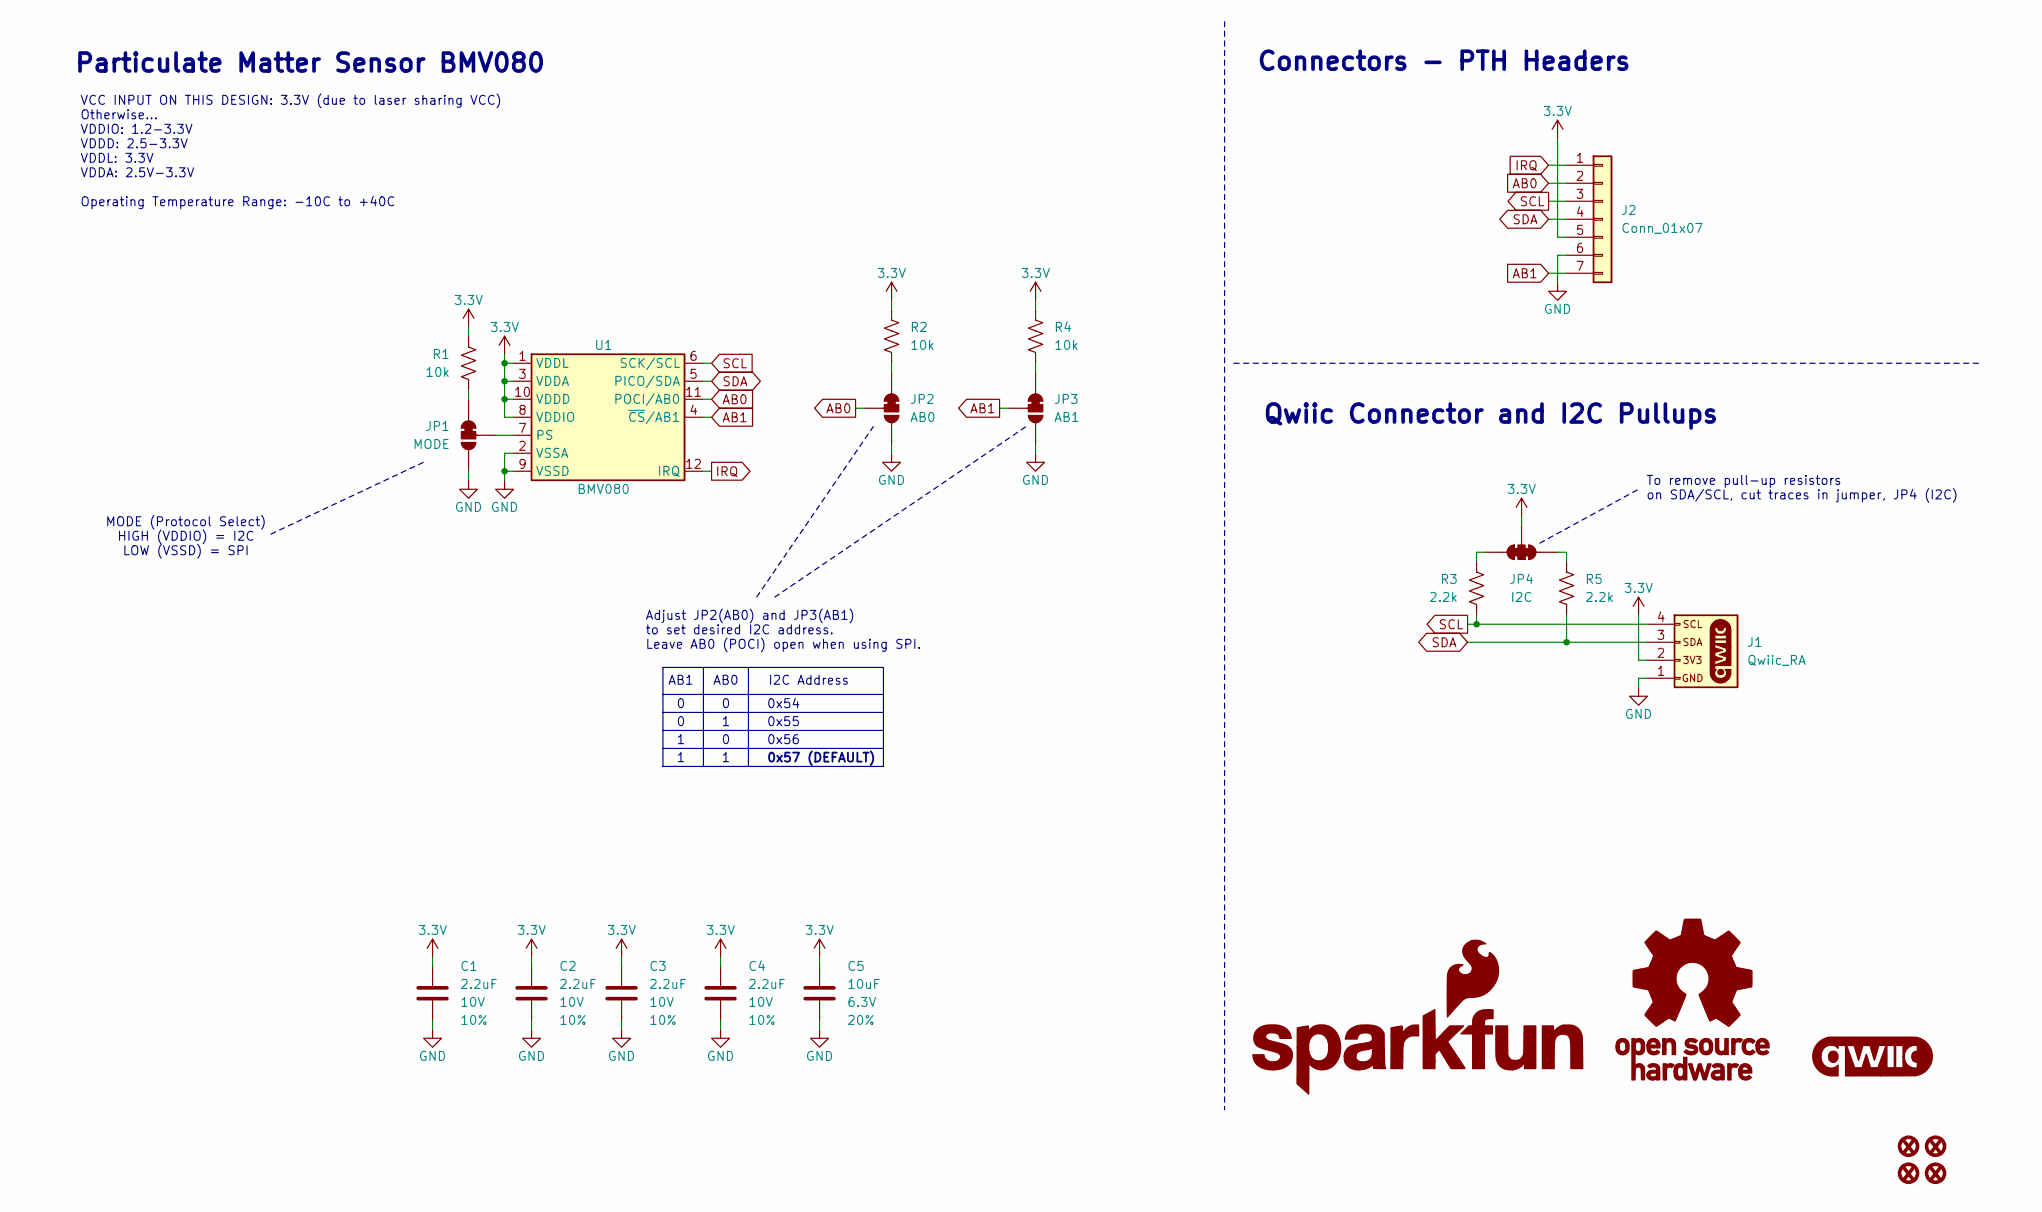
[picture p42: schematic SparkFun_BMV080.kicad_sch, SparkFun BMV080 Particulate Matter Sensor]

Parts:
C1, C2, C3, C4: 2.2uF; C_0402_1005Metric; Voltage 10V; Tolerance 10%
C5: 10uF; C_0603_1608Metric; Voltage 6.3V; Tolerance 20%
FID1, FID2, FID3, FID4: Fiducial_0.5mm; Fiducial_0.5mm_Mask1mm
G1: OSHW_Logo; Creative_Commons_License
G2: SparkFun_Logo
G3: qwiic_Logo
J1: Qwiic_RA; JST_SMD_1.0mm-4_RA
J2: Conn_01x07; 1x07
JP1: MODE; Jumper_3_NC-1_Trace_NoSilk
JP2: AB0; Jumper_3_NC-1_Trace_NoSilk
JP3: AB1; Jumper_3_NC-1_Trace_NoSilk
JP4: I2C; Jumper_3_NC-2_Trace_NoSilk
R1, R2, R4: 10k; R_0402_1005Metric
R3, R5: 2.2k; R_0402_1005Metric
U1: BMV080; FPC_0.3mm-13

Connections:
3.3V: C1.1, C2.1, C3.1, C4.1, C5.1, J1.2, J2.5, JP4.2 (C), R1.1, R2.1, R4.1, U1.1 (VDDL), U1.3 (VDDA), U1.8 (VDDIO), U1.10 (VDDD)
AB0: J2.2, JP2.2 (C), U1.11 (POCI/AB0)
AB1: J2.7, JP3.2 (C), U1.4 (~CS/AB1)
GND: C1.2, C2.2, C3.2, C4.2, C5.2, J1.1, J2.6, JP1.3 (B), JP2.3 (B), JP3.3 (B), U1.2 (VSSA), U1.9 (VSSD)
IRQ: J2.1, U1.12 (IRQ)
unnamed: JP1.1 (A), R1.2
unnamed: JP1.2 (C), U1.7 (PS)
unnamed: JP2.1 (A), R2.2
unnamed: JP3.1 (A), R4.2
unnamed: JP4.1 (A), R5.2
unnamed: JP4.3 (B), R3.2
SCL: J1.4, J2.3, R3.1, U1.6 (SCK/SCL)
SDA: J1.3, J2.4, R5.1, U1.5 (PICO/SDA)

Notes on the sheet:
0x54
MODE (Protocol Select) HIGH (VDDIO) = I2C LOW (VSSD) = SPI
AB1
Connectors - PTH Headers
0x57 (DEFAULT)
VCC INPUT ON THIS DESIGN: 3.3V (due to laser sharing VCC) Otherwise... VDDIO: 1.2-3.3V VDDD: 2.5-3.3V VDDL: 3.3V VDDA: 2.5V-3.3V Operating Temperature Range: -10C to +40C
Particulate Matter Sensor BMV080
AB0
0x56
I2C Address
Adjust JP2(AB0) and JP3(AB1) to set desired I2C address. Leave AB0 (POCI) open when using SPI.
0x55
To remove pull-up resistors on SDA/SCL, cut traces in jumper, JP4 (I2C)
Qwiic Connector and I2C Pullups

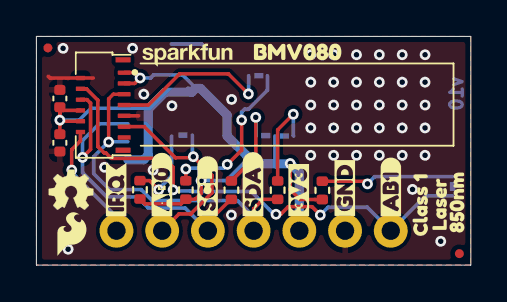
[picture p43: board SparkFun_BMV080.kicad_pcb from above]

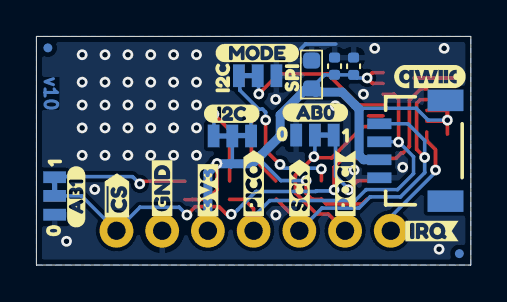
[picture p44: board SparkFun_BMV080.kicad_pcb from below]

Board: 2 copper layers, 24.1 x 12.7 mm, 51 parts (27 on the bottom side), 13 nets.

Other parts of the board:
Ref**: Val**; OSHW_Logo_2.5mm
kibuzzard-66BFB450: G***; kibuzzard-66BFB450
kibuzzard-66BFBF9D, kibuzzard-66BFBF9D#2: G***; kibuzzard-66BFBF9D
kibuzzard-66BFBF23: G***; kibuzzard-66BFBF23
kibuzzard-66BFBF70, kibuzzard-66BFBF70#2: G***; kibuzzard-66BFBF70
kibuzzard-66BFC0D2: G***; kibuzzard-66BFC0D2
kibuzzard-66BFC2FE: G***; kibuzzard-66BFC2FE
kibuzzard-66BFC09F: G***; kibuzzard-66BFC09F
kibuzzard-66BFC045: G***; kibuzzard-66BFC045
kibuzzard-66BFC108: G***; kibuzzard-66BFC108
kibuzzard-66BFC288: G***; kibuzzard-66BFC288
kibuzzard-66C3B2A1: G***; kibuzzard-66C3B2A1
kibuzzard-66C3B2DA: G***; kibuzzard-66C3B2DA
kibuzzard-66C3B2FA, kibuzzard-66C3B2FA#2: G***; kibuzzard-66C3B2FA
kibuzzard-66C3B3B1: G***; kibuzzard-66C3B3B1
kibuzzard-66C3B3D3: G***; kibuzzard-66C3B3D3
kibuzzard-66C3B30A, kibuzzard-66C3B30A#2: G***; kibuzzard-66C3B30A
kibuzzard-66C3B31E: G***; kibuzzard-66C3B31E
kibuzzard-66C3B369: G***; kibuzzard-66C3B369
kibuzzard-66C4B81D: G***; kibuzzard-66C4B81D
kibuzzard-66C7A36E: G***; kibuzzard-66C7A36E
kibuzzard-66C77290: G***; kibuzzard-66C77290
kibuzzard-67250BE2: G***; kibuzzard-67250BE2
kibuzzard-67250CD2: G***; kibuzzard-67250CD2
kibuzzard-67250CEE: G***; kibuzzard-67250CEE

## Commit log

2024-08-16 Layout work
    [FPC_0.3mm-13_MOLEX_503566-1302.step, SparkFun_BMV080.kicad_pcb, SparkFun_BMV080.kicad_sch]
2024-08-19 moved hw files into Hardware folder
    [FPC_0.3mm-13_MOLEX_503566-1302.step, SparkFun_BMV080.kicad_pcb, SparkFun_BMV080.kicad_sch]
2024-08-19 schematic cleanup and reroute
    -added section divider lines and section titles
    -jumper reference and naming corrected, rotated text in sch to all horizontal
    -added company and defined by:
    -rearranged part name and value texts for calrity
    -moved logos in sch to proper location
    -moved to vertical qwiic connector
    -added decoupling caps
    -added exposed copper for potential heat sink
    -added silk to jumpers
    -added qwiic logo to silk
    -added version v01 to bottom copper
    [SparkFun_BMV080.kicad_pcb, SparkFun_BMV080.kicad_sch]
2024-08-20 changed bypass caps to larger value of 2.2uF
    -bypass caps bumped up from 1.0uF to 2.2uF as per recommended in datasheet
    [SparkFun_BMV080.kicad_pcb, SparkFun_BMV080.kicad_sch]
2024-08-20 jumpers to no silk outline and prod_id on ic
    [SparkFun_BMV080.kicad_pcb, SparkFun_BMV080.kicad_sch]
2024-08-20 measures and more
    -add measures
    -add copper finish
    -add ordering instructions
    -DRC fixes
    [SparkFun_BMV080.kicad_pcb]
2024-08-20 grid and molex connector FP correction
    -set grid origin point to top left of PCB edge
    -corrected molex connecto FP - width of mounting pads X position was 2.52 and now is 2.51
    [SparkFun_BMV080.kicad_pcb]
2024-08-20 nudged via next to mounting pad for DRC correction
    [SparkFun_BMV080.kicad_pcb]
2024-08-20 molex connector outline in FP
    [SparkFun_BMV080.kicad_pcb]
2024-08-20 molex fp work
    -removed extra **VAL text object
    -moved INSERT THIS END to user.1
    -added connector ds link in the FP
    [SparkFun_BMV080.kicad_pcb]
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2024-08-20 corrected position of NC pin 13 in symbol
    [SparkFun_BMV080.kicad_sch]
2024-08-20 CSB is active low in symbol
    [SparkFun_BMV080.kicad_pcb, SparkFun_BMV080.kicad_sch]
2024-08-21 pre-review last second updates
    -added VCC input requirements and ranges into sch
    -added temp range to sch
    -added pin 1 indicator silk to molex connector
    -added extra GRND trace connection on pad 2 of molex connector
    [SparkFun_BMV080.kicad_pcb, SparkFun_BMV080.kicad_sch]
2024-08-21 sensor position outline correction and more
    -added F.Fab and F.Silk outline for sensor - to help with correctly showing position on PCB
    -changed PROD_ID to connector for the sensor
    -made v01 in copper "knockout" style
    -adjusted F.Mask to match the area of the sensor we are supposed to use thermal tape on
    -adjusted B.Mask to match our small heat sink.
    [HMV080_2D_Dimensional_top_down-Sketch.dxf, SparkFun_BMV080.kicad_pcb, SparkFun_BMV080.kicad_sch]
2024-08-21 added SFE and OSHW logos
    [SparkFun_BMV080.kicad_pcb]
2024-08-21 dimensions update and resistor line up
    [SparkFun_BMV080.kicad_pcb]
2024-08-21 moved AB1/CS header onto 0.5 grid for perf board/breadboard
    [SparkFun_BMV080.kicad_pcb]
2024-08-22 checklist run eng
    -sch tightening
    -sch jumpers text notes
    -set solder mask expansion to 0.05mm
    -added active low line on top of CS label silk
    -SCL silk label set to input end flag type
    [SparkFun_BMV080.kicad_pcb, SparkFun_BMV080.kicad_sch]
2024-08-22 acid trap fix on gnd connection coming off Molex
    [SparkFun_BMV080.kicad_pcb]
2024-08-22 -tiny tweaks before ordering v01
    -updated measures on AB1 header
    -updated F.FAB drawing of plastic on molex to better estimate reflow position
    -moved NC into symbol box to avoid accidentally netting to it
    -CSB is now CS with a line
    -SCK clock silk label is round
    [SparkFun_BMV080.kicad_pcb, SparkFun_BMV080.kicad_sch]
2024-08-22 proto panel 2x2 of v01
    [SparkFun_BMV080.kicad_pcb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]
2024-08-23 panel v01b - meet size requirement for vscores
    -expanded outer tabs to meet 70mmx70mm requirement for vscores
    [SparkFun_BMV080_panelized.GBL, SparkFun_BMV080_panelized.GBO, SparkFun_BMV080_panelized.GBP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]
2024-10-21 housing design - slot style v26
    [SparkFun_BMV080.step]
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2024-11-01 v02 pcb protos v29a enclosure
    -RA qwiic connector
    -removed standoffs
    -single pth header row now includes CS
    -moved pth header upwards to clear enclosure slot
    -decreased width from 1 inch to 0.95 inch
    [SparkFun_BMV080.kicad_pcb, SparkFun_BMV080.kicad_sch]
2024-11-01 PCB dimensions updated/added
    [SparkFun_BMV080.kicad_pcb]
2024-11-01 update libraries and 3d models
    [SparkFun_BMV080.kicad_pcb, SparkFun_BMV080.step]
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2024-11-14 bumping version to v10
    [SparkFun_BMV080.kicad_pcb, SparkFun_BMV080.kicad_sch]
2024-11-14 pre-review changes
    -adjusted 3.3V pads route away on FPC to avoid oddities and promote even reflow.
    -added gnd via near AB1 header to avoid GND pour antenna.
    -pulled trace away from I2C jumper to avoid slicing.
    -nudged via to avoid acid trap near AB0 jumper.
    -nudges via near SDA pad on FPC to avoid acid trap
    [SparkFun_BMV080.kicad_pcb]
2024-11-14 FPC 3d model position correction
    [SparkFun_BMV080.kicad_pcb]
2024-11-14 Added sensor 3d model
    [SparkFun_BMV080.kicad_pcb]
2024-11-15 Update 3D model
    [SparkFun_BMV080.kicad_pcb]
2024-11-25 Changed C5 from DNP to populated
    [SparkFun_BMV080.kicad_pcb, SparkFun_BMV080.kicad_sch]
2024-11-25 ordering instructions updated to RED
    [SparkFun_BMV080.kicad_pcb]
2024-11-25 production pcb panel v10
    [SparkFun_BMV080_panelized.GBL, SparkFun_BMV080_panelized.GBO, SparkFun_BMV080_panelized.GBP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]
2024-11-26 V32 housing - unify parts and exported STL files
    -V32 housing design verified on inhouse resin printer
    -unified (aka Fusion in freeCAD) bodies to a single body for mesh export as STL
    -utilized higher precision settings for TSL export (surface dev: 10um, angular dev: 10deg)
    -created ZIP file of both STL files (inner and outer shell) for quotes
    [SparkFun_BMV080.step]
2024-11-26 demo mounting board design WIP
    [Alphanumeric_Dimensional_Mounting.FCStd, Demo_Mounting_Board.FCStd, ESP32_ThingPlus_C_Dimensional_Mounting.FCStd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]
2024-12-11 housing - re-created stl files for proto order 1 from JLC
    -these files were used on the 1st proto order from jlc3dp
    -they are a single shell and have higher output resolution
    -renamed to smaller length name (JLC didn't like long name on the upload)
2024-12-11 demo mounting board DXF v02
    -switched BMV080 and alphanewmeric display, so BMV080 is on the left. This will work better with any text I raster into the plexiglass plate.
    [Demo_Mounting_Board.FCStd, HMV080_Demo_Mounting_Board_v02.dxf]
2024-12-12 demo board mesh outputs as STL
    [Alphanumeric_Dimensional_Mounting_001 (Meshed).stl, Demo_Mounting_Board.FCStd, ESP32_ThingPlus_C_Dimensional_Mounting_001 (Meshed).stl]
2024-12-19 demo mounting board update for oled 1.3 inch
    [Demo_Mounting_Board-Body001Sketch001.dxf, Demo_Mounting_Board.FCStd, SparkFun_Qwiic_OLED_13_Dimensional_Mounting.FCStd]
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2024-12-20 o-ring cover slot box, and pcb slot tightening
    -Changed to o-ring style "cover slot box"
    -Width of PCB slot was 14.2, now is 13.8.
    -Height of PCB flex mounds was 0.25mm, now is 0.45mm
2024-12-20 tightening of outer shell cavity
    -reduced x and y each by 0.2mm (was 17.8x28.14, now is 17.6x27.94)
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2024-12-21 IS_4D - tightest snap fit pin rail style
2024-12-21 IS_5D Medium tightness snap fit pin rail style
2024-12-21 IS_5D least tightness snap fit rail style
2025-01-07 flex mounds increased to a true 0.45mm height
    -previously, they were actually 0.38mm (the bezie position dot above the line was 0.45mm)
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2025-01-09 IS_VM_1D
    IS_VM_1D:
    snap-fit pin Z_pos = snap-fit hole Z_pos
    snap-fit pin H = 0.5mm
    pcb-flex-mound H = 0.45mm
2025-01-09 IS_VM_2D
    IS_VM_2D:
    snap-fit pin H = 0.6mm
    pcb-flex-mound H = 0.55mm
    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
2025-01-09 IS_VM_3D
    IS_VM_3D:
    snap-fit pin H = 0.7mm
    pcb-flex-mound H = 0.65mm
    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
2025-01-10 mod sensor opening cut to avoid thin area
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2025-01-30 Add Some Assets
    [SparkFun_BMV080_v10_3D_model.step]
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2025-01-31 PTH Header fillet slot opening
    -added a slot to the inner shell, to allow clearance for when using PTH male header pins.
    -Also added a "thickener" bit of material above the slot, so that the wall will fab better.
    -Also cut out a cavity of the outer shell to allow space for the new thickener rectangle.
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2025-02-04 Corrected thin wall on IS (under glass mount)
    -Corrected a thin wall near the sensor opening.
    -This was caused when I scooted the sensor opening over 0.5mm, but failed to also scoot over the "slot-cut" material below.
    -bumped the version text cutter to v11 (inside shell design only)
    -exported mesh
    -zipped with ordering instructions.
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2025-02-10 ISv12, OSv11, wall thickening
    -The left/right walls of the o-ring mount were 0.66mm thick (which is below JLCs threshold [0.8mm]). They are now 1.05mm.
    -opened up OS cavity above the o-ring mount box to work with the modified IS.
    -also adjusted the version text cutouts to be less deep - to avoid wall thickness warnings.
2025-03-20 Enclosure files organized by file type (STEP/FreeCAD/STL)
    [91772A106_Passivated 18-8 Stainless Steel Pan Head Phillips Screw.STEP, BMV080_Enclosure_Part_A_Inside_Shell_V12.stl, BMV080_Enclosure_Part_B_Outside_Shell_V11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]
2025-03-21 library work
    -moved bmv080 sensor symbol and footprint to sparkfun libraries with pending PR.
    -updated symbol and footprints in kicad design files
    -note, the sensor itself and the FPC connector are now separate things. The BMV080 has an "outline" footprint that is placed at the same origin point as the sensor (and includes the 3d model of the s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
    [SparkFun_BMV080.kicad_pcb, SparkFun_BMV080.kicad_sch]
2025-03-27 Update quickstart.md
    Fixing quick start assembly image size & adding links for OLED & Alphanumeric examples.
2025-03-28 Update STEP file
    -step file now includes the 3d model of the sensor
    -also updated some library work around the FPC and sensor step files
    [SparkFun_BMV080.kicad_pcb]
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

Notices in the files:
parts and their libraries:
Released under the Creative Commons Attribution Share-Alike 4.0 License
